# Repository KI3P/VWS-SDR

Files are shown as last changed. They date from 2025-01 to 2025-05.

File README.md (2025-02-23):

# Vienna Wireless Society Software Defined Receiver (VWS-SDR)

This repository contains the files for a 2025 project by the [Vienna Wireless Society's](https://viennawireless.net/wp/) Makers Group. This project aims to build the RF front end of a software defined receiver covering the HF bands. The goals of the project are: 

1. Learn how to use KiCAD, and 
2. Learn surface mount assembly techniques. 

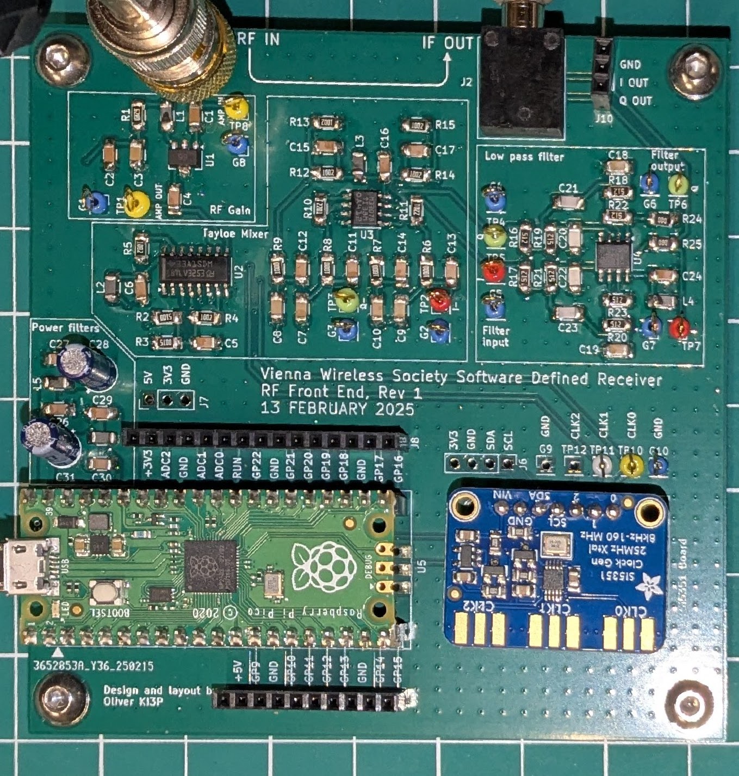
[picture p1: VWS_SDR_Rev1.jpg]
Photo of the VWS SDR


## Credit

The VWS-SDR design draws heavily from the RF board of the T41-EP Software Defined Transceiver (SDT) originally designed by Al Peter-AC8GY and Jack Purdum-W8TEE. The T41-EP is a self-contain SDT that does not require an external PC, laptop, or tablet to use. Al and Jack wrote a book, available on [Amazon](https://www.amazon.com/dp/B0D25FV48C), describing the theory and operation of the T41-EP.

Thanks to Rick W1DSP for writing the Quisk integration, Barry KV4FV for the gnuradio demodulation flowgraph, the many T41 contributors for the hardware and software derived from that project, and to Leon NT8B, Dean KK4DAS, Mark KM4GML, Vlad K4LRZ, and Ed KQ4RVX for their help designing, building, and testing the prototypes.

## Design overview 

The VWS-SDR has stages shown in the block diagram below.

1. A gain stage based on the [GALI-S66+](https://www.minicircuits.com/WebStore/dashboard.html?model=GALI-S66%2B) MMIC amplifier.
2. A [Tayloe Mixer](http://norcalqrp.org/files/Tayloe_mixer_x3a.pdf) that uses quadrature signals generated by a [Si5351](https://www.digikey.com/en/htmldatasheets/production/1316951/0/0/1/si535x-tmstk) clock generator and a [74CBTLV3253](https://www.ti.com/product/SN74CBTLV3253) 2-channel analog multiplexer to mix the RF signals to IF.
3. An anti-aliasing low-pass filter followed by a USB soundcard to digitize the IF signal.
4. Demodulation is performed in software using [quisk](http://james.ahlstrom.name/quisk/) or [gnuradio](https://www.gnuradio.org/).

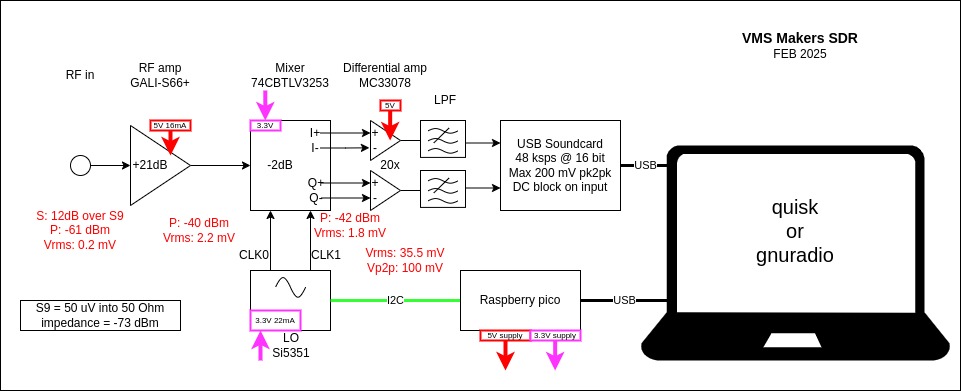
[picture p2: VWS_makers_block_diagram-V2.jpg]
Block diagram for the VWS SDR


To modify the PCB design, download this repository to your computer. Open the `KiCad\VWS-SDR-ref-design.kicad_pro` file using the [KiCad](https://www.kicad.org/) EDA software package. This repository includes a few custom symbols and footprints that should automatically be added to your library lists by KiCad.

## Code

### Pico

You two equivalent choices for the code that will run on the Pico. If you prefer C code written in the Arduino framework, use that. If you prefer micropython code, load that code instead. 

#### Arduino framework

The `code/pico_sketch` folder contains an Arduino sketch to program the Pico. The sketch listens for ASCII commands on the USB serial bus (baud 115200) that match this format:

`FR 123456`

where `123456` is the frequency in Hertz that the Si5351 should be tuned to.

Open the sketch in the Arduino IDE and configure Arduino to have the settings shown below under the Tools menu. For “Port” select whatever COM port appears when you plug the Pico into your computer with a USB cable.

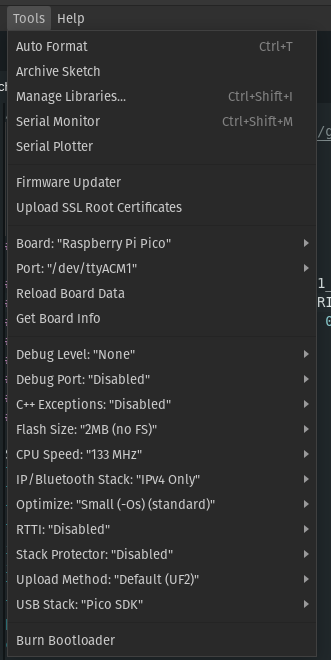
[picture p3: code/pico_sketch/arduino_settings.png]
Configuration settings for arduino


Then compile and load the sketch onto the pico by clicking the Upload button (Sketch->Upload).

The Pico sketch configures the Si5351 to produce 10 MHz tones on start. You can confirm this by connected an oscilloscope to the CLK0 and CLK1 outputs where you should see something like the screen shot below.

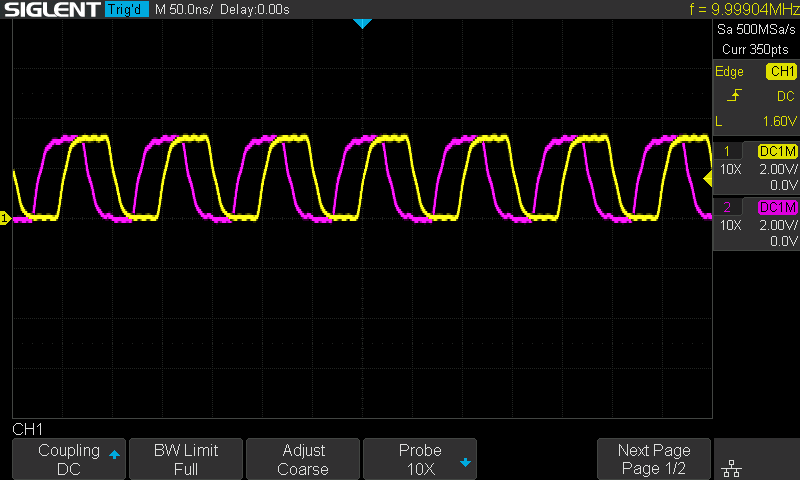
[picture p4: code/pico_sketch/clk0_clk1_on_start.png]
CLK0 and CLK1 on start


You can manually change the frequency using the Serial Monitor window in the Arduino. The Pico communicates at a baud rate of 115200 and expects commands in the form: “FR 123456” where 123456 is the frequency in Hz.

For instance, to tune the center of the band to 7070 kHz, enter the following command:

Update the tune frequency using the Arduino serial monitor

You should get the reply “OK” and an invitation to enter a new frequency. The CLK0 and CLK1 outputs should now show an output at 7070 kHz.

The expected response when updating the frequency

#### Micropython framework

The `code/pico_micropython` folder contains micropython code for the Pico written by Rick W1DSP. It works similarly to the Arduino sketch, the only difference is commands are terminated by a newline (`\n`) in the Python code, versus carriage return (`\r`) in the sketch. If the preferred tuner is the sketch, just edit this line in `code/VWS-Quisk/vwsquiskpkg/quisk_hardware.py`:

```python
   self.serial.write(b'FR %d\r'%(vfo+correction))
```

And change to `\r` to `\n`.  The original thinking in using Python for the VWS was to facilitate the extensive driver libraries Adafruit provides for their peripherals, as well as the ease of use and velocity of development Python brings to low speed control applications.

To install the Python tuner, the Pico must first be loaded with CircuitPython as described [here](https://learn.adafruit.com/getting-started-with-raspberry-pi-pico-circuitpython/circuitpython). Once CircuitPython is installed and booted, you will see a virtual disk drive for the board appear.  On my machine it is `/media/rick/CIRCUITPY`.

To run the tuner, copy `code/pico_micropython/{code.py,vws_tuner.py}`
to the virtual disk drive, and power cycle the board.  To verify operation, connnect to the serial port associated with the board (here, it is `/dev/ttyACM0`, 115200 bps), and type a carriage return.  You should see a `tune>` prompt, and entering a command like `FR 7074000` will cause the 5351 to tune to 7.074 Mhz. As required by the VWS SDR designs, clk0/clk1 are in quadrature. The Python script works similarly to various 5351 libraries to generate quadrature clocks: PLLA is a integer multiple of the desired frequency (factor of 4).

### Computer

Demodulation of the audio can be done in gnuradio or Quisk.

#### Gnuradio

Credit to Barry KV4FV for his contributions to the gnuradio code.

The `code/gnuradio_KI3P` contains a [gnuradio](https://wiki.gnuradio.org/index.php/InstallingGR) flowgraph to display the received signal and perform audio demodulation. It also allows you to adjust the gain and phase balance between the L and R channels to improve sideband separation if needed.

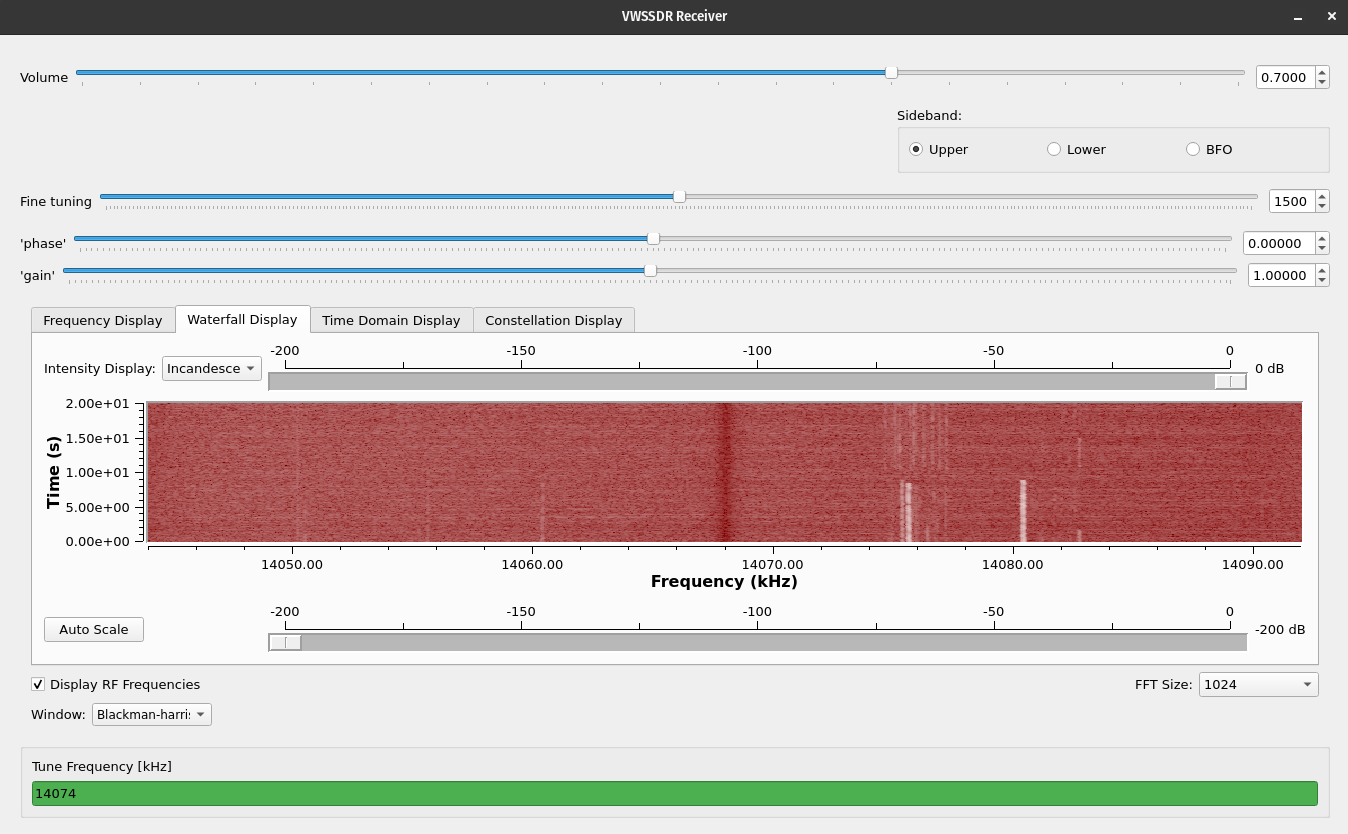
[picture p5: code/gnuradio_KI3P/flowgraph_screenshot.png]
Screenshot of the gnuradio flowgraph


#### Quisk

Credit to Rick W1DSP for the Quisk code and instructions. Quisk links:

* [Quisk documentation](https://james.ahlstrom.name/quisk/docs.html)
* [Quisk github](https://github.com/jimahlstrom/quisk)
* [Install Quisk](https://james.ahlstrom.name/quisk/docs.html#Installation)

##### Install VWS-Quisk package

Once quisk is installed, copy the `code/VWS-Quisk/vwsquiskpkg` directory into the quisk distribution directory. On my computer this is:

* `/usr/lib/python3/dist-packages/quisk`

Note: This is the way new radios are introduced to the quisk radio configuration manager: for a new radio named `xyzzy`, you create a directory named `xyzzypkg` in the quisk directory, and write a `quisk_hardware.py` module.  Python class inheritance will define most of the necessary routines, but functionally you'll want open/close/tune method as shown in the `vwsquiskpkg` version.

##### Configure Quisk

Launch quisk.

To add the VWS SDR as a radio, click the Config Button, then select the Radios tab. In the Radios config panel, select the "Add a new radio with the general type", and select the VWS SDR item, name the radio "VWS"

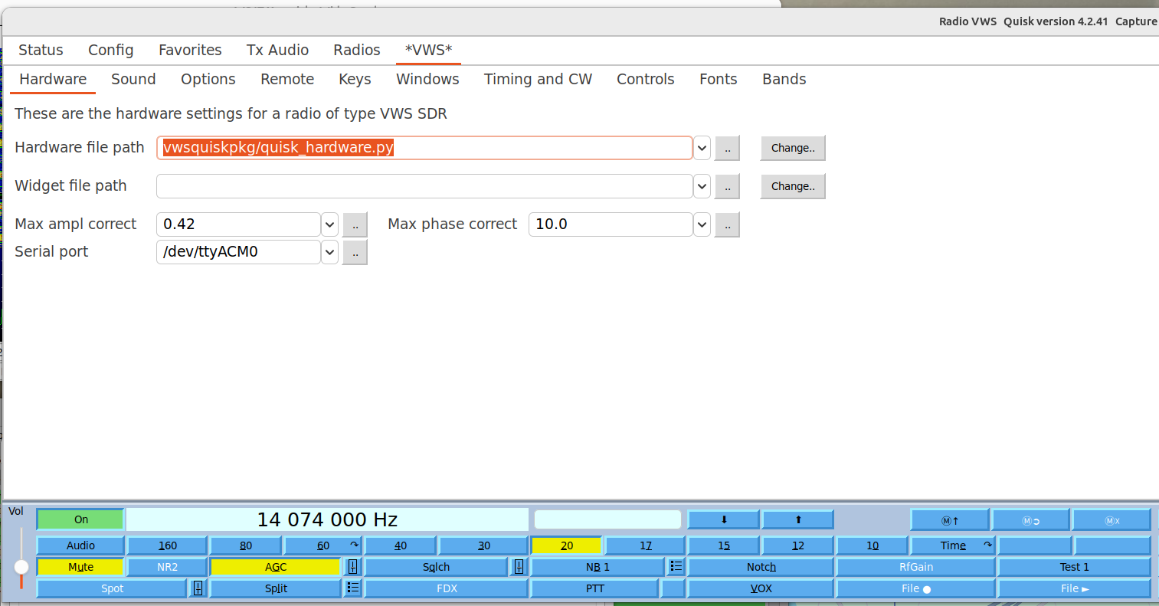
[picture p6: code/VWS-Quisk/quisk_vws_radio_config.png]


You should see a new Radio appear just below the title bar named "VWS".  Click that item, and then select the Hardware tab.  Enter the serial port name (in my case it was `/dev/ttyACM0`). Click the Sound tab, and choose appropriate settings for "Radio Sound Output" and "Microphone Input" that correspond to your soundcard.  In Digital Rx0 line, select `pulse: Use name QuiskDigitalOutput.monitor`.  Of course, you'll need to have loaded the pulse audio system.  Note that I have not tested any of this on Mac or Windows, and wouldn't expect it to work out of the box on either system type.

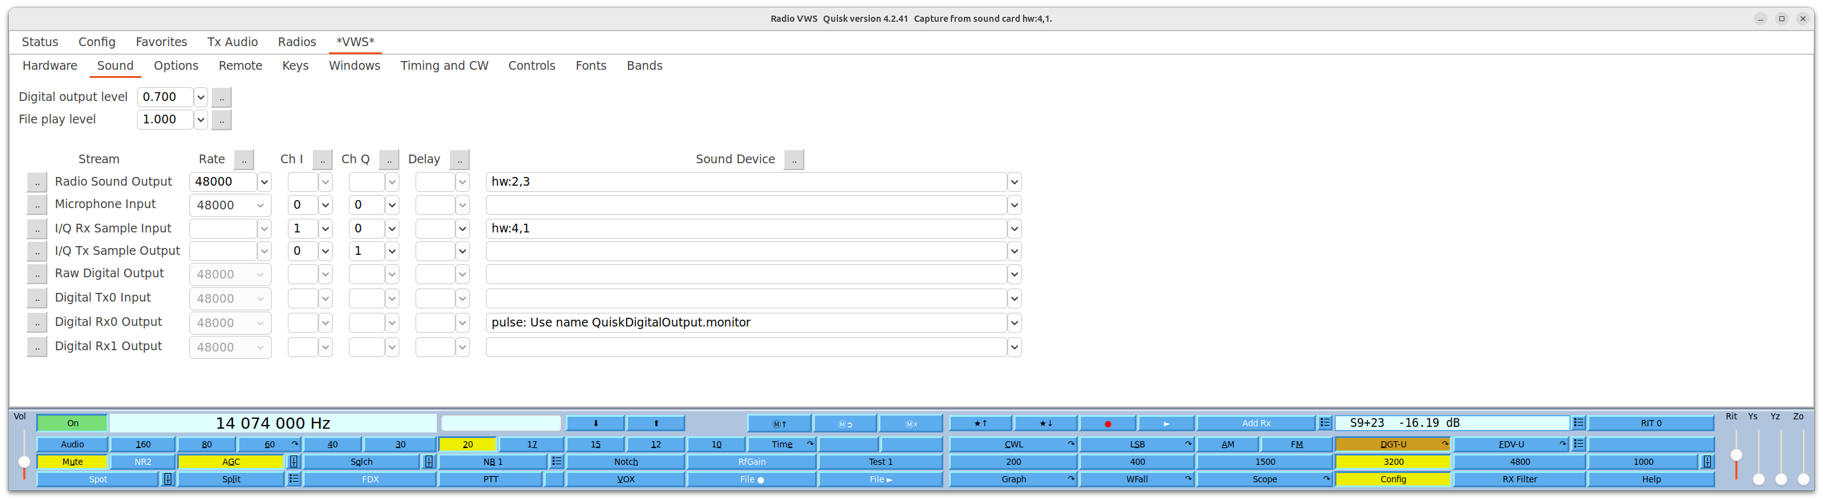
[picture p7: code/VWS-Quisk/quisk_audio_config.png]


Back on the Config->Radios screen, select VWS in the "When Quisk starts, use the radio" line. In the Config tab, quisk provides the ability to adjust IQ balance via "Adjust receive amplitude and phase".  I manually adjusted this using a signal generator tuned to the vicinity of 14.074 mhz, and then saved the result.

##### Configure WSJT-X if desired

To use the WSJT-X integration, use the package manager to install wsjtx, or build from source. 

I've been starting wsjtx manually within quisk: Click Config, select the Config tab, then look for the Start WSJT-X item.  The drop down menu has an option Main Rx0 Now item - select that and quisk will start the wsjtx application.  Once you've fully debugged the quisk:wsjtx integration,
setting "Start WSJT-X" to "Main Rx0 on startup" on the Config menus, Config tab will automatically start up wstjx when quisk starts.

The included screen captures show some of the details of getting quisk to interoperate with wsjtx.  Note that quisk won't stream audio on `QuiskDigitalOutput.monitor` unless you're in a digital mode (see DGT-U).

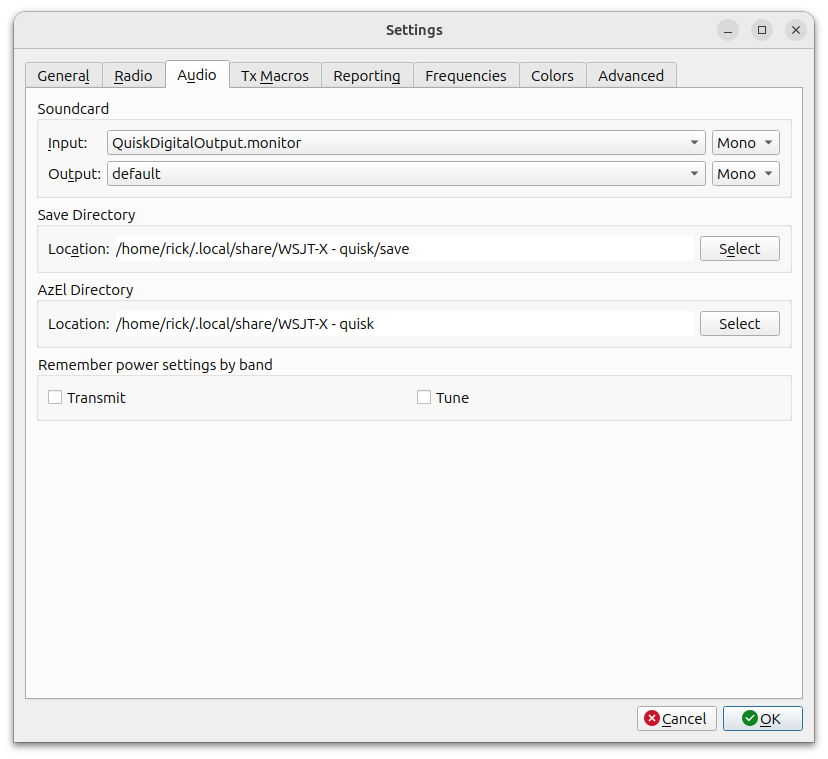
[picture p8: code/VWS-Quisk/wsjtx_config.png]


Quisk can be controlled by hamlib.  In the Config screens, select the VWS radio, then Remote tab.  On the Remote config screen, set the port to 4532.  You'll have to restart quisk for the setting to take effect.  After this is done, you can use `rigctl -m 2` to test: for example, the command `F 14074000` will tune quisk to the FT8 band on 20M.  Once the hamlib integration has been confirmed as working, you'll be able to control quisk via the wsjtx application, i.e. switching bands, frequencies in that app, and quisk following along as a normal radio would.

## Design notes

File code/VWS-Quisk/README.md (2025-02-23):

Lab notebook on how I got quisk to operate with the VWS-SDR:

---- Install tuner software on VWS SDR
I use a Python tuner on the Pico to tune the SDR.  It works similarly to the Arduino sketch in the
KI3P git repo, the only difference is commands are terminated by a newline (\n) in the Python
code, versus carriage return (\r) in the sketch.  If the preferred tuner is the sketch, just
edit this line in vwsquiskpkg/quisk_hardware.py:

   self.serial.write(b'FR %d\r'%(vfo+correction))

And change to \r to \n.  The original thinking in using Python for the VWS was to facilitate the
extensive driver libraries Adafruit provides for their peripherals, as well as the ease of use
and velocity of development Python brings to low speed control applications.

To install the Python tuner, the Pico must first be loaded with CircuitPython as described
here https://learn.adafruit.com/getting-started-with-raspberry-pi-pico-circuitpython/circuitpython.
Once CircuitPython is installed and booted, you will see a virtual disk drive for the board
appear.  On my machine it is /media/rick/CIRCUITPY.

To run the tuner, copy vws_tuner/{code.py,vws_tuner.py}
to the virtual disk drive, and power cycle the board.  To verify operation, connnect to the
serial port associated with the board (here, it is /dev/ttyACM0, 115200 bps), and type a
carriage return.  You should see a tune> prompt, and entering a command like FR 7074000
will cause the 5351 to tune to 7.074 mhz.  As required by the VWS SDR designs, clk0/clk1
are in quadrature.  The Python script works similarly to various 5351 libraries to generate
quadrature clocks: PLLA is a integer multiple of the desired frequency (factor of 4).

My eventual goal is to eliminate the need for a sound board and get IQ sent over USB to quisk
directly.  The current state of CircuitPython may not support bulk data transfer via USB, and
if so, I'll likely switch to using the Raspi SDK to write an appropriate driver.

---- Install quisk
Quisk documentation:  https://james.ahlstrom.name/quisk/docs.html
Quisk github: https://github.com/jimahlstrom/quisk
Build Quisk according to https://james.ahlstrom.name/quisk/docs.html#Installation

Once quisk is built, copy the included vwsquiskpkg directory into the quisk distribution directory (I run
quisk in the build location).

Note: This is the way new radios are introduced to the quisk radio configuration manager: for a new radio
named xyzzy, you create a directory named xyzzypkg in the quisk directory, and write a quisk_hardware.py
module.  Python class inheritence will define most of the necessary routines, but functionally you'll want
open/close/tune method as shown in the vwsquiskpkg version.

From the command line "python3 quisk.py" will start quisk.

---- Configure Quisk
To add the VWS SDR as a radio, click the Config Button, then select the Radios tab.
In the Radios config panel, select the "Add a new radio with the general type", and select the VWS SDR item,
name the radio "VWS"

You should see a new Radio appear just below the title bar named "VWS".  Click that item,
and then select the Hardware tab.  Enter the serial port name (in my case it was /dev/ttyACM0).
Click the Audio tab, and choose appropriate settings for "Radio Sound Output" and "Microphone
Input".  In Digital Rx0 line, select pulse: Use name QuiskDigitalOutput.monitor.  Of couse,
you'll need to have loaded the pulse audio system.  Note that I have not tested any of this
on Mac or Windows, and wouldn't expect it to work out of the box on either system type.

Back on the Config Radios screen, select VWS in the "When Quisk starts, use the radio" line.

In the Config tab, quisk provides the ability to adjust IQ balance via "Adjust receive amplitude
and phase".  I manually adjusted this using a signal generator tuned to the vicinity of 14.074 mhz,
and then saved the result.

---- Configure WSJT-X if desired
To use the WSJT-X integration, use the package manager to install wsjtx, or build from source.

I've been starting wsjtx manually within quisk: Click Config, select the Config tab, then look for the
Start WSJT-X item.  The drop down menu has an option Main Rx0 Now item - select that and
quisk will start the wsjtx application.  Once you've fully debugged the quisk:wsjtx integration,
setting "Start WSJT-X" to "Main Rx0 on startup" on the Config menus, Config tab will automatically
start up wstjx when quisk starts.

The included screen captures show some of the details of getting quisk to interoperate with
wsjtx.  Note that quisk won't stream audio on QuiskDigitalOutput.monitor unless you're
in a digital mode (see DGT-U).

Quisk can be controlled by hamlib.  In the Config screens, select the VWS radio, then
Remote tab.  On the Remote config screen, set the port to 4532.  You'll have to restart
quisk for the setting to take effect.  After this is done, you can use rigctl -m 2 to
test: for example, the command "F 14074000" will tune quisk to the FT8 band on 20M.  Once
the hamlib integration has been confirmed as working, you'll be able to control quisk
via the wsjtx application, i.e. switching bands, frequencies in that app, and quisk following
along as a normal radio would.

----
I've not provided a "LICENSE" for any of this work, as it is mostly just a few learnings about
how to get Quisk working with the VWS SDR.  Any IP contained herein may be used for free and
for any purpose, and as usual, I'm to be held harmless for its use.

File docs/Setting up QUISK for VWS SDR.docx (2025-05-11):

Setting up QUISK for VWS SDR

KK4DAS – 5/11/2025

1. Install python (add python to PATH, use admin privileges)
  a. Python Release Python 3.13.2 | Python.org (https://www.python.org/downloads/release/python-3132/)
2. Install quisk:
  a. Run PowerShell (not PowerShell ISE)
  b. Confirm Python version:
    i. python –version
  c. Install quisk
    i. python -m pip install --upgrade pip python -m pip install --upgrade setuptools python -m pip install --upgrade wxPython python -m pip install --upgrade pyserial python -m pip install --upgrade quisk
3. Add a desktop shortcut. Right click on the desktop and select New -> Shortcut. In the popup windows enter “python -m quisk” and hit Next, on the next screen enter “Quisk” and press finish.
4. Install the VWS radio package in the quisk installation directory
  a. To find the quisk installation directory right click on the new shortcut and select “Properties”. Look for the “Start in” field. This is the Python installation directory. Here is what it looks like on mine:
  b. C:\Users\dsoul\AppData\Local\Programs\Python\Python313
  c. In your file manager navigate to that directory, then navigate to the folder “Lib/site-packages/quisk”. This is the Quisk installation directory.
  d. Copy the folder “vwsquisk” package from the project folder that you downloaded from github. Its in the folder ,,/code/VWS-Quisk.
5. ---- Configure Quisk
  a. To add the VWS SDR as a radio, click the Config Button, then select the Radios tab.
  b. In the Radios config panel, select the "Add a new radio with the general type", and select the VWS SDR item, name the radio "VWS" and click “Apply”
  c. Click “When Quist starts, use the radio” to VWS
  d. You should see a new Radio appear just below the title bar named "VWS". Click that item, and then select the Hardware tab. Enter the serial port name (in my case it was COM5).
  e. Click the Sound tab, and choose appropriate settings for "Radio Sound Output" and "Microphone Input". For Radio Sound Output choose whatever your default sound output is. To find the device to use for “Microphone Input” in Windows, open System -> Sound Settings and find the name of the Input device that shows up when you plug in your USB sound card or your default stereo microphone input if available. Back in Quisk select this on “Microphone Input”
  f. Verify that the sound rate for output and input are both 48000
  g. Scroll down… for “I/Q Rx Sample Input” change Channel I to 1, and Channel Q to 0
  h. Select the Waterfall button.
  i. Shutdown and restart Quisk for all changes to take effect and you should be up and running.
6. --- Troubleshooting
  a. If the COM port is not set right QUISK may not start. After configuration in the GUI QUISK settings are stored in your Documents folder in a file called: quisk_settings.json. You can edit that file with Notepad and make any changes you need there. You can also delete all quisk files in the Documents folder and then start QUISK again and re-do the configuration steps.
  b. If QUISK fails to start you can run QUISK from a command prompt to see the error messages. Open a Command Prompt and enter:

pythonw -m quisk

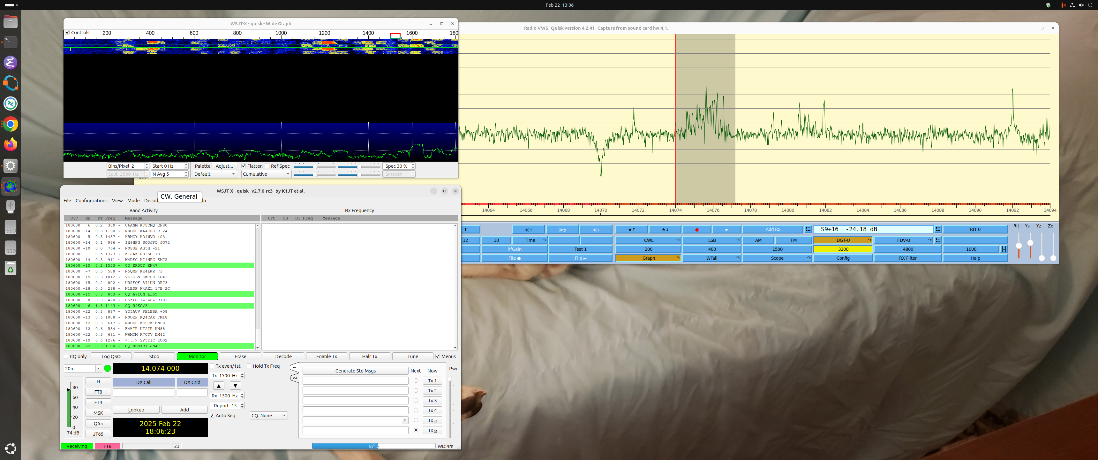
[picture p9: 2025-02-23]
code/VWS-Quisk/wsjtx_quisk_vws_sdr.png

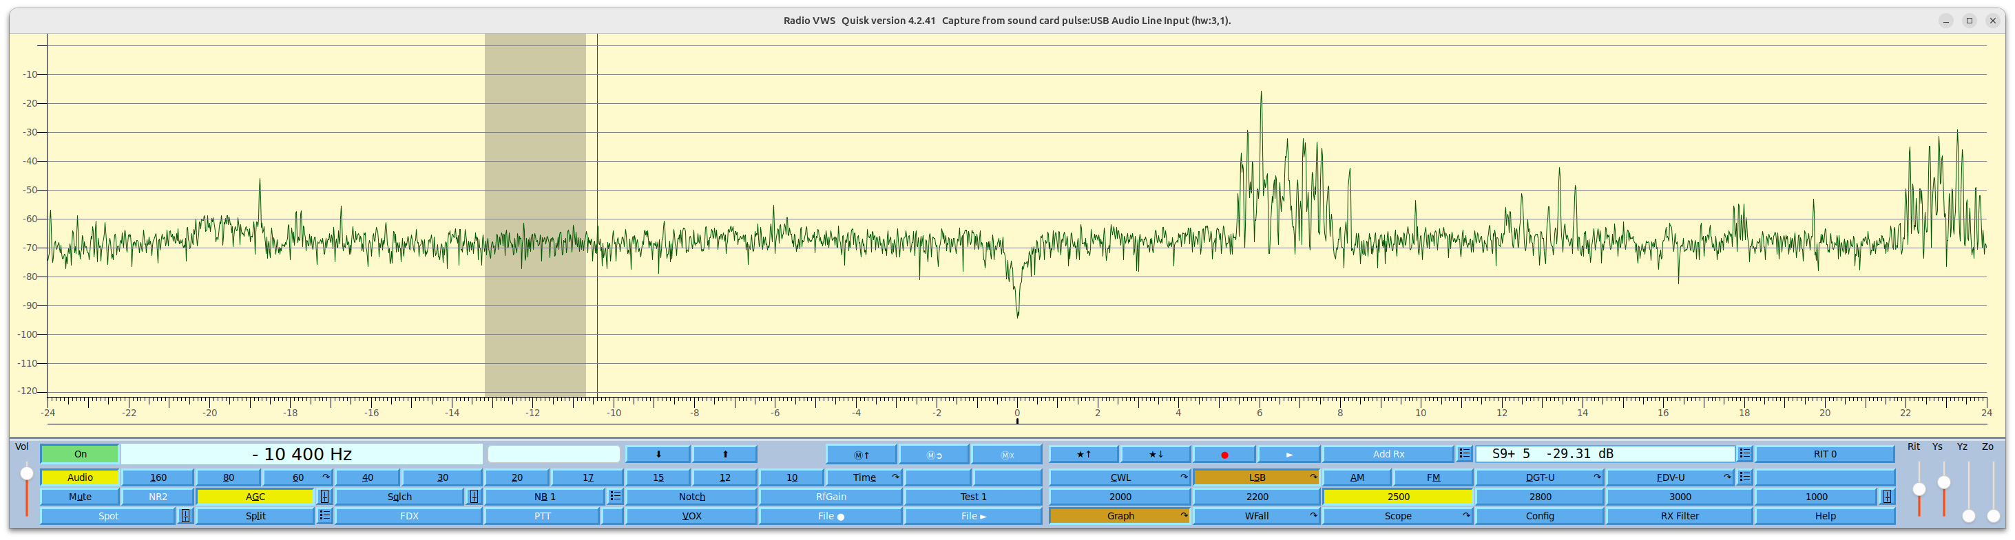
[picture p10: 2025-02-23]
code/VWS-Quisk/quisk_w1dsp_14070.png

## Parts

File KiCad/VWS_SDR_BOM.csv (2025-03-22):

Reference | Value | Footprint | Qty | DNP | Tayda | Adafruit PN | MPN
C1,C2,C4,C5,C6,C15,C16,C17,C24,C27,C30 | 0.1uF | Capacitor_SMD:C_1206_3216Metric_Pad1.33x1.80mm_HandSolder | 11 |  |  |  | C1206C104K5RACTU
C3,C18,C19 | 10uF | Capacitor_SMD:C_1206_3216Metric_Pad1.33x1.80mm_HandSolder | 3 |  |  |  | C1206C106K4PACTU
C7,C8,C9,C10 | 1uF | Capacitor_SMD:C_1206_3216Metric_Pad1.33x1.80mm_HandSolder | 4 |  |  |  | KGM31HR71C105KU
C11,C12,C13,C14,C26,C29 | 10nF | Capacitor_SMD:C_1206_3216Metric_Pad1.33x1.80mm_HandSolder | 6 |  |  |  | C1206C103K5RAC7210
C20,C22 | 180pF | Capacitor_SMD:C_1206_3216Metric_Pad1.33x1.80mm_HandSolder | 2 |  |  |  | KGM31BCG2A181FT
C21,C23 | 105pF | Capacitor_SMD:C_1206_3216Metric_Pad1.33x1.80mm_HandSolder | 2 |  |  |  | C3216C0G2J101G060AA
C28,C31 | 4.7uF | Capacitor_THT:CP_Radial_D5.0mm_P2.00mm | 2 |  |  |  | ESK475M016AC3AA
D1 | 5V LED | LED_SMD:LED_1206_3216Metric_Pad1.42x1.75mm_HandSolder | 1 |  |  |  | APTD3216LCGCK
D2 | 3V3 LED | LED_SMD:LED_1206_3216Metric_Pad1.42x1.75mm_HandSolder | 1 |  |  |  | APTD3216LSYCK
D3 | Indicator | LED_SMD:LED_1206_3216Metric_Pad1.42x1.75mm_HandSolder | 1 |  |  |  | APTD3216LSYCK
G1,G2,G3,G4,G5,G6,G7,G8,G9,G10,TP1,TP2,TP3,TP4,TP5,TP6,TP7,TP8,TP10,TP11,TP12,TP19,TP20 | TestPoint | Connector_PinHeader_2.54mm:PinHeader_1x01_P2.54mm_Vertical | 23 | DNP
J1 | RF_IN | VWS-SDR:SMA_Vertical_and_Edgemount | 1 |  |  |  | CONSMA001-G
J2 | IQ_Out | VWS-SDR:Jack_3.5mm_STX-3081_Horizontal | 1 |  |  |  | SJ1-3515N
J3 | SI5351 board | VWS-SDR:Adafruit_Si5351 | 1 |  |  | 2045
J4,J5 | Conn_01x20_Socket |  | 2 |  | A-1310
J6 | I2C breakout | Connector_PinHeader_2.54mm:PinHeader_1x04_P2.54mm_Vertical | 1 | DNP
J7 | Power breakout | Connector_PinHeader_2.54mm:PinHeader_1x03_P2.54mm_Vertical | 1 | DNP
J8 | GPIO Breakout1 | Connector_PinSocket_2.54mm:PinSocket_1x15_P2.54mm_Vertical | 1 |  | A-1669
J9 | GPIO Breakout2 | Connector_PinSocket_2.54mm:PinSocket_1x10_P2.54mm_Vertical | 1 |  | A-1306
J10 | IF breakout | Connector_PinSocket_2.54mm:PinSocket_1x03_P2.54mm_Vertical | 1 |  | A-1069
L1 | 1.5uH | Resistor_SMD:R_1206_3216Metric_Pad1.30x1.75mm_HandSolder | 1 |  |  |  | LQM31PN1R5M00L
L2,L3,L4,L5,L6 | FB | Resistor_SMD:R_1206_3216Metric_Pad1.30x1.75mm_HandSolder | 5 |  |  |  | HZ1206E601R-10
R1 | 62R | Resistor_SMD:R_1206_3216Metric_Pad1.30x1.75mm_HandSolder | 1 |  |  |  | CR1206-FX-62R0ELF
R2,R3 | 510R | Resistor_SMD:R_1206_3216Metric_Pad1.30x1.75mm_HandSolder | 2 |  |  |  | CR1206-FX-5100ELF
R4,R5,R12,R13,R14,R15 | 10k | Resistor_SMD:R_1206_3216Metric_Pad1.30x1.75mm_HandSolder | 6 |  |  |  | CR1206-FX-1002ELF
R6,R7,R8,R9 | 100R | Resistor_SMD:R_1206_3216Metric_Pad1.30x1.75mm_HandSolder | 4 |  |  |  | CR1206-FX-1000ELF
R10,R11 | 2k2 | Resistor_SMD:R_1206_3216Metric_Pad1.30x1.75mm_HandSolder | 2 |  |  |  | CR1206-FX-2201ELF
R16,R17,R18,R19,R20,R21,R22,R23 | 5k1 | Resistor_SMD:R_1206_3216Metric_Pad1.30x1.75mm_HandSolder | 8 |  |  |  | CR1206-JW-512ELF
R24,R25 | 0 | Resistor_SMD:R_1206_3216Metric_Pad1.30x1.75mm_HandSolder | 2 |  |  |  | CRCW12060000Z0EAC
R26 | 3k | Resistor_SMD:R_1206_3216Metric_Pad1.30x1.75mm_HandSolder | 1 |  |  |  | CR1206-FX-3001ELF
R27,R28 | 1k5 | Resistor_SMD:R_1206_3216Metric_Pad1.30x1.75mm_HandSolder | 2 |  |  |  | CR1206-FX-1501ELF
TPa1 | LNA Bias | TestPoint:TestPoint_Pad_D1.5mm | 1
TPc1 | Mixer Enable | TestPoint:TestPoint_Pad_D1.5mm | 1
TPd1 | Mixer DC | TestPoint:TestPoint_Pad_D1.5mm | 1
TPe1 | Q offset | TestPoint:TestPoint_Pad_D1.5mm | 1
TPf1 | I offset | TestPoint:TestPoint_Pad_D1.5mm | 1
TPg1 | Amp DC | TestPoint:TestPoint_Pad_D1.5mm | 1
TPh1 | Filter DC | TestPoint:TestPoint_Pad_D1.5mm | 1
U1 | GALI-S66 | Package_TO_SOT_SMD:SOT-89-3 | 1 |  |  |  | GALI-S66+
U2 | 74CBTLV3253DR | Package_SO:SOIC-16_3.9x9.9mm_P1.27mm | 1 |  |  |  | SN74CBTLV3253DR
U3,U4 | MC33078 | Package_SO:SOIC-8_3.9x4.9mm_P1.27mm | 2 |  |  |  | MC33078DR
U5 | RASPBERRY-PICO | VWS-SDR:Raspberry_pico_pin_or_castellation_footprint | 1 |  |  |  | SC0915

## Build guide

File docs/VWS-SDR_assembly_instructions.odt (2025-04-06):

VWS SDR Assembly Instructions

V2, 5 April 2025

When soldering surface mount components by hand, start with the lowest profile components – those that stick out the least from the PCB. Once all surface mount components are soldered, proceed to the through hole components. If a surface mount component has one end connected to ground, solder that end first.

# Solder the surface mount components

1. Solder the SMD capacitors.
2. Solder the SMD resistors.
3. Solder the SMD inductors (L1 and FB).
4. Solder the semiconductors (U1 to U4)

For U1, the GALI-S66 amplifier, first solder pin 1 (indicated by the triangle on the silkscreen), followed by the pin 3 pad on the opposite side of the component. Then solder the center pad, which is connected to ground. Have patience when soldering the grounded pads – you will need to apply heat for much longer to achieve good solder flow because of the heat flow from the pads into the ground plane.

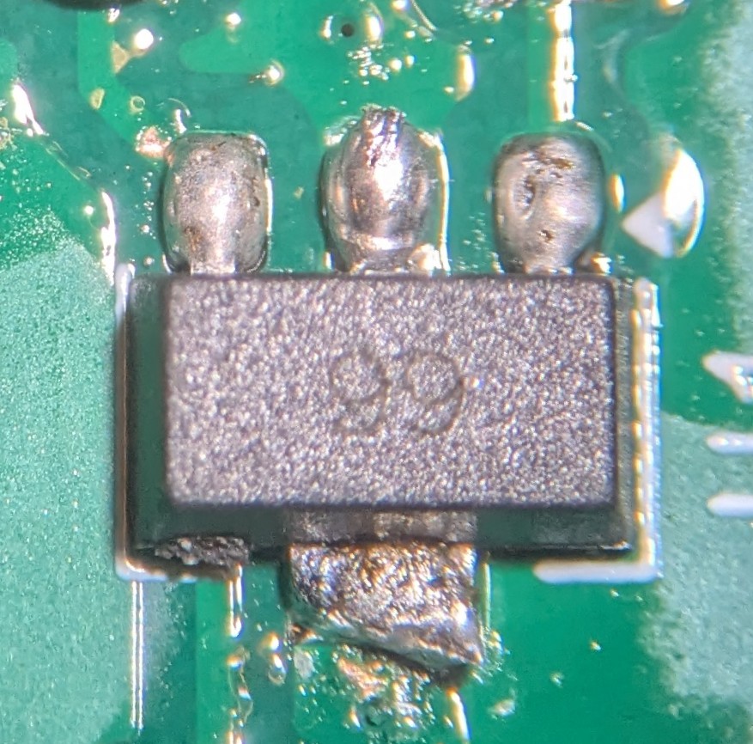
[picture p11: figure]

# Solder the through-hole components

1. Solder J2, the IF out connector.
2. Solder J3, the header pins for the Si5351 board.
3. If you want to use header sockets, solder them for the GPIO breakouts and the Pico. Otherwise, solder the header pins for the Pico.
4. Solder J1, the RF input SMA connector.
5. Solder C28 and C31, the through-hole capacitors.
6. Connect or solder the Pico and Si5351 boards.

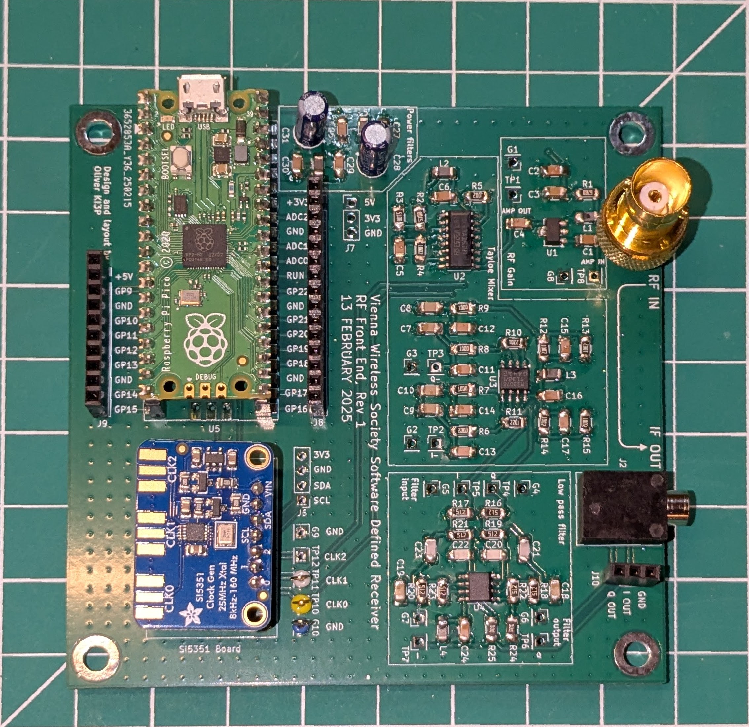
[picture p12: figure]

# Power on and test

The board should draw roughly 80 mA of current from the USB cable. Measure this with a USB current meter if you have one.

## Pico sketch

If you have a VWS-SDR kit, the Pico has been pre-loaded with the appropriate Arduino sketch. To get the latest version, download it from the following link:

https://github.com/KI3P/VWS-SDR/tree/main/

Click the green box that says CODE and select Download Zip and save the file on the computer. Unzip the file to wherever you want – you’ll need to navigate there to update the sketch.

## Installing and configuring the Arduino IDE

If you don’t have it first download and install the Arduino IDE:

https://www.arduino.cc/en/software

Start the Arduino IDE.

Install the board manager for the Raspberry PI Pico.

In the File menu select Preferences. A dialog box will open. In the field “Additional Board Manager URLs:” cut and paste the following link and click OK.

https://github.com/earlephilhower/arduino-pico/releases/download/global/package_rp2040_index.json

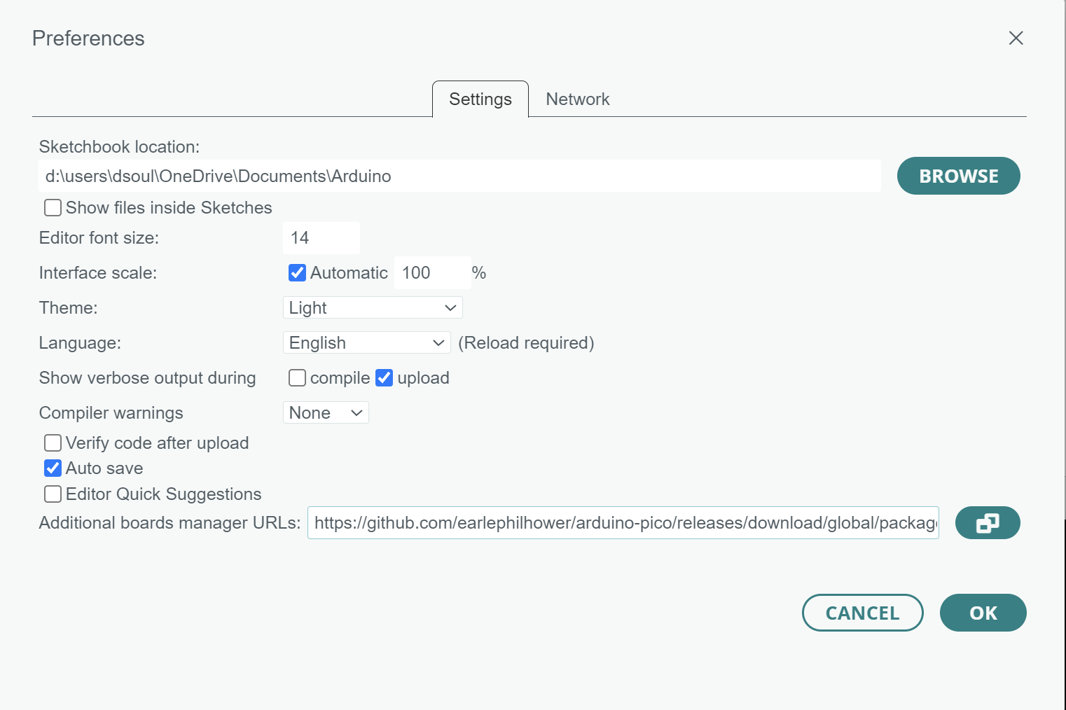
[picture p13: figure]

Next, go to Tools -> Boards -> Board manager and search for Pico and a list of board managers will appear. The one you want is “Raspberry PI Pico/RP2040 by Earle F. Philhower III”. Click INSTALL.

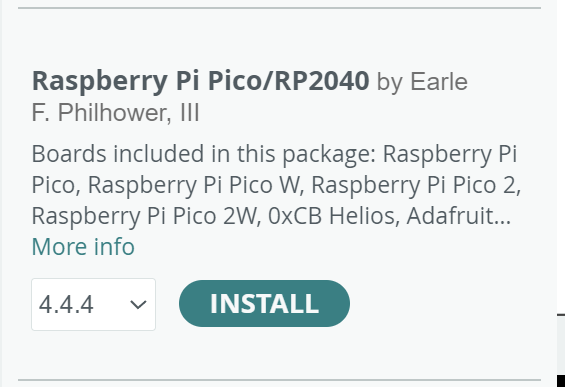
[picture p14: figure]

Now open the sketch. Navigate on your computer to the folder where you unzipped the code archive, find and open the pico sketch folder, then double click on pico_sketch.ino and the sketch will open in the Arduino IDE.

If you have not done so already, connect the Pico to your computer via a USB cable.

In the Arduino IDE go to Tools -> Board -> Board Manager -> Raspberry Pi Pico/RP2040 and select Raspberry Pi Pico.

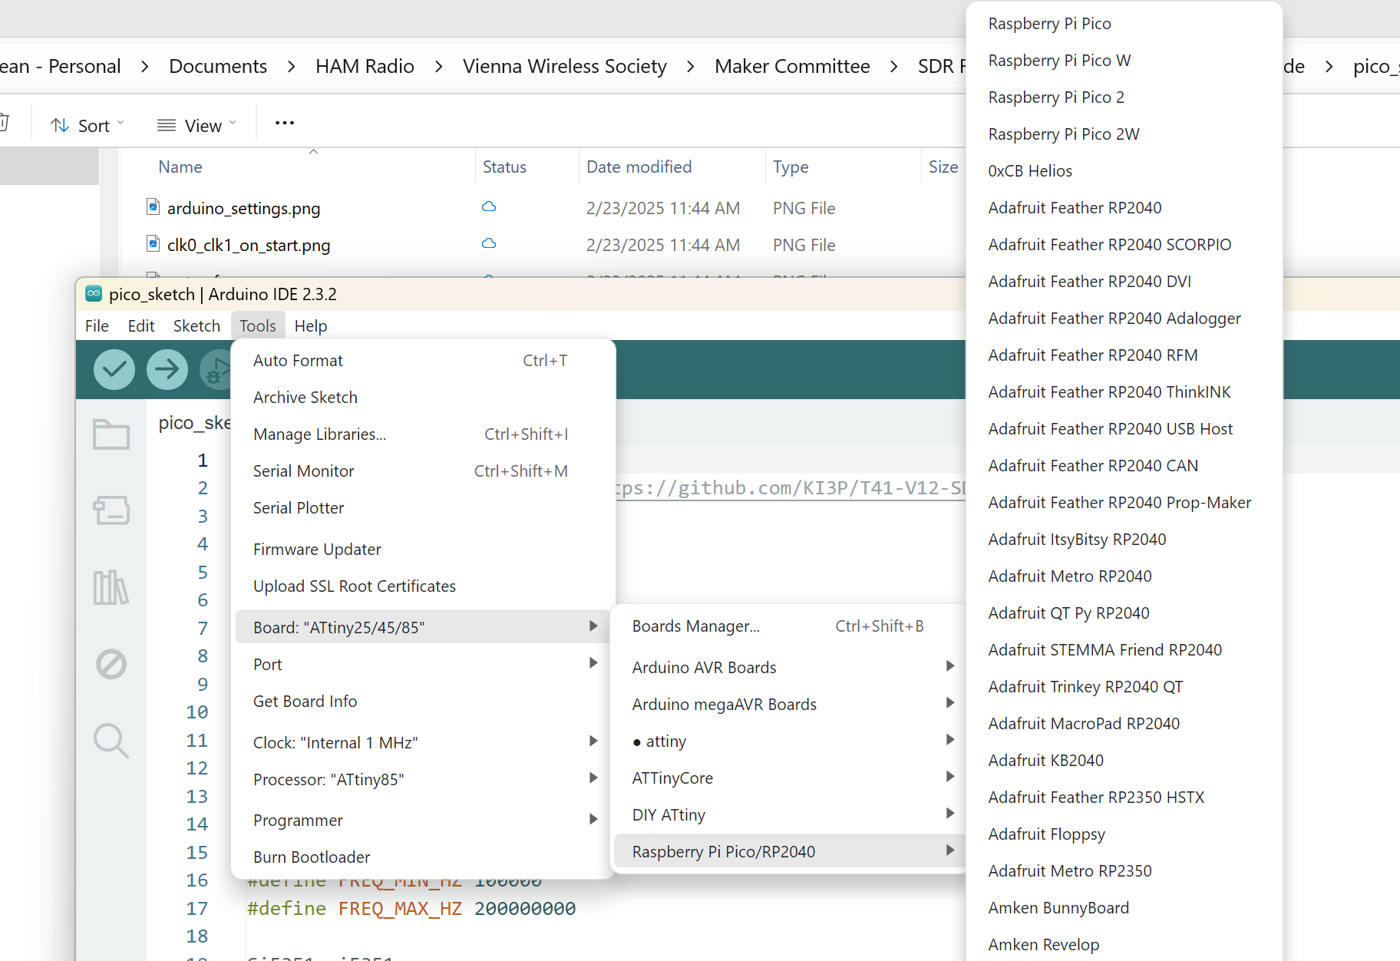
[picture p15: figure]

Open the sketch in the Arduino IDE and configure Arduino to have the settings shown below under the Tools menu. For “Port” select whatever COM port appears when you plug the Pico into your computer with a USB cable:

* Tools -> Port and select the COM port connected to the Pico.

To compile and upload the sketch to Pico, click the Right arrow on the top toolbar in the IDE.

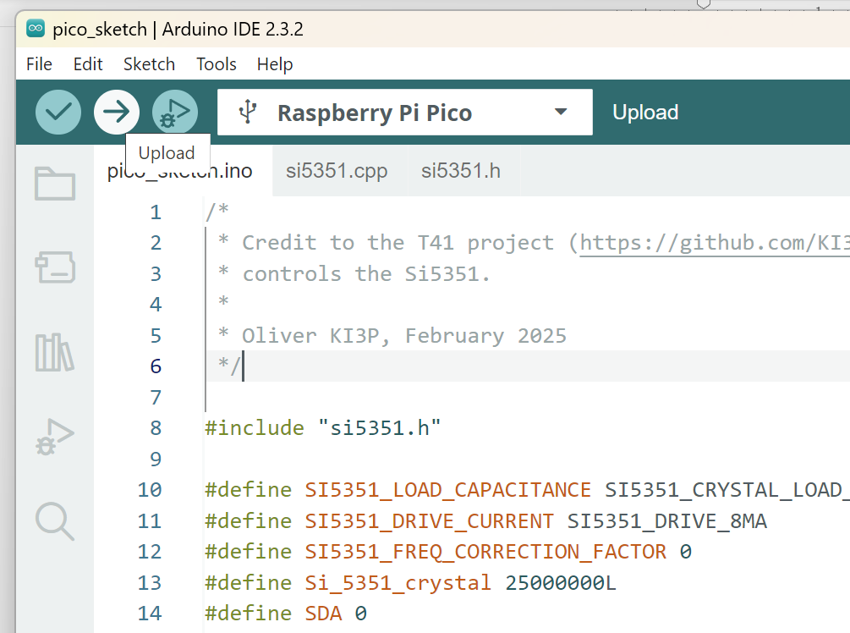
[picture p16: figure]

That’s it. You now have the latest sketch on the Raspberry PI Pico and you are ready to test and are all set for future updates.

## Testing

The Pico sketch configures the Si5351 to produce 10 MHz tones on start. You can confirm this by connecting an oscilloscope to the CLK0 and CLK1 outputs where you should see something like the screen shot below.


You can manually change the frequency using the Serial Monitor window in the Arduino. The Pico communicates at a baud rate of 115200 and expects commands in the form: “FR 123456” where 123456 is the frequency in Hz.

For instance, to tune the center of the band to 7070 kHz, enter the following command:

You should get the reply “OK” and an invitation to enter a new frequency. The CLK0 and CLK1 outputs should now show an output at 7070 kHz.

## Demodulation

Connect the IF output (J2) to the microphone input on the sound card of your computer. We will use gnuradio to test whether the SDR is producing signals that can be demodulated. The gnuradio sketch can be found at the following link:

https://github.com/KI3P/VWS-SDR/tree/main/code/gnuradio_KI3P

To install gnuradio on your computer follow these instructions:

https://wiki.gnuradio.org/index.php/InstallingGR

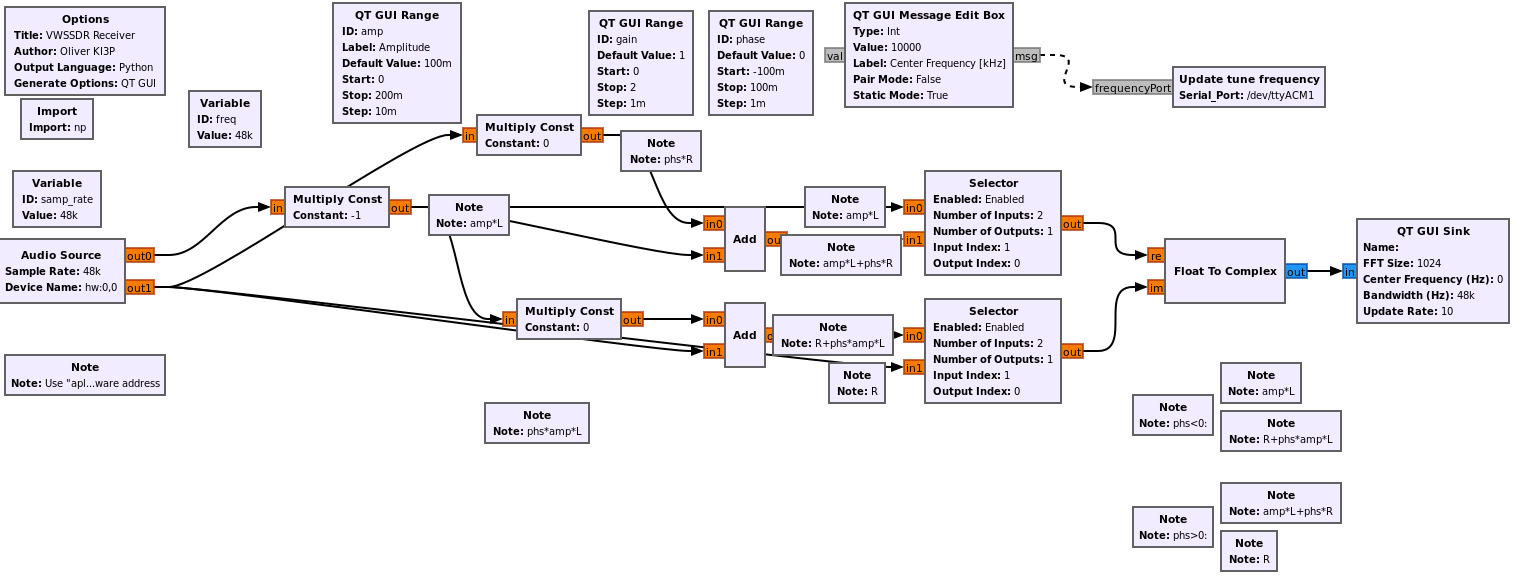
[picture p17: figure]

You will need to update two fields in the gnuradio sketch for your computer setup. The first is the address of the sound card in the Audio Source block on the left. By default it is set to the first audio device. This may work out of the box for your computer. If not, then you can use the “aplay -l” command in linux to find the hardware address of your sound card device.

To find the Microphone Input name in Windows, open Settings and go to System and then Sound. Look for the input devices and find the name windows uses for the device you are using and copy that into the GNU radio field. You can also rename the device to something there if that makes it easier.

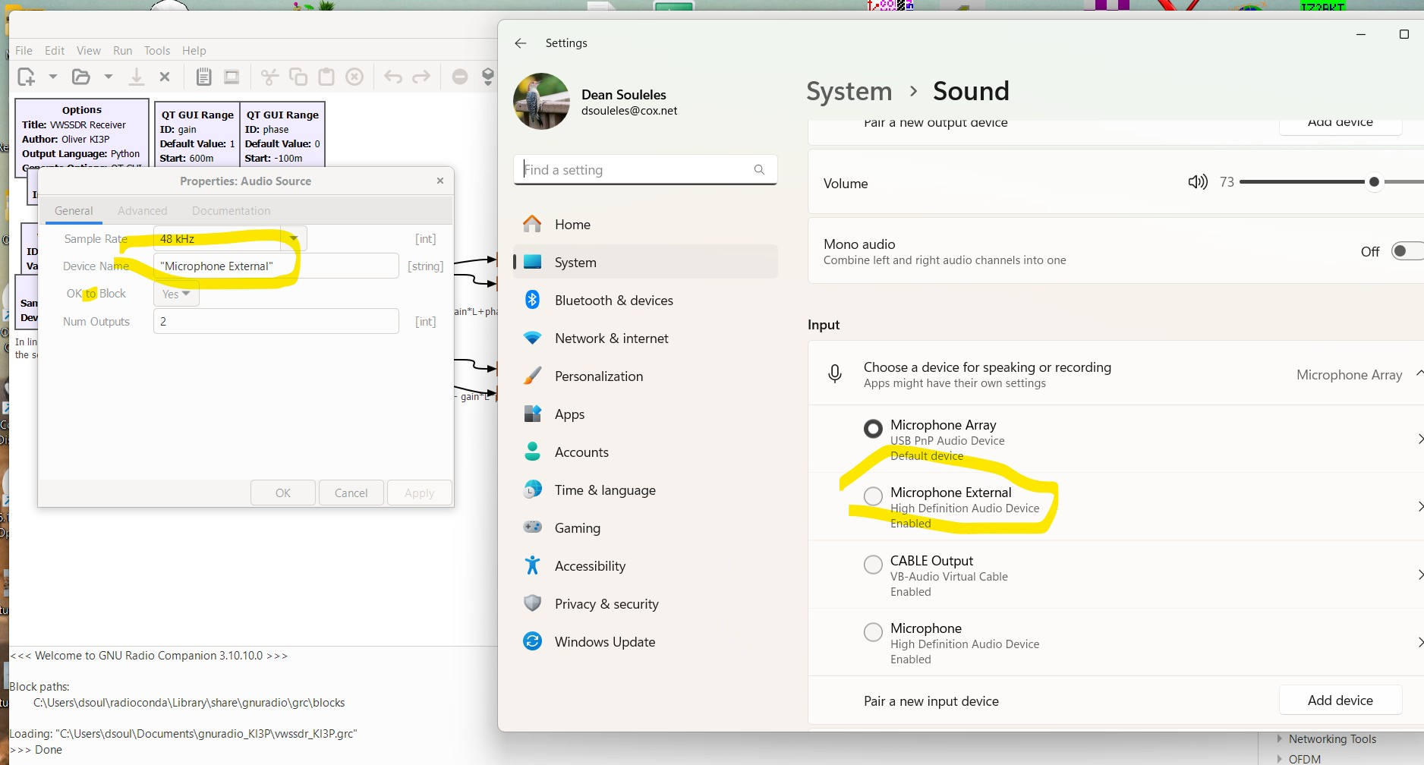
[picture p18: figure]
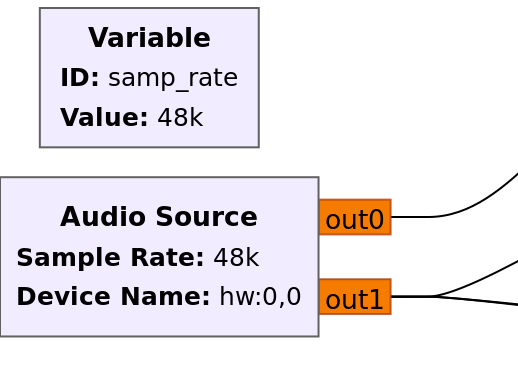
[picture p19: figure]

The second field that will need to be updated is the serial COM port address of the Pico.

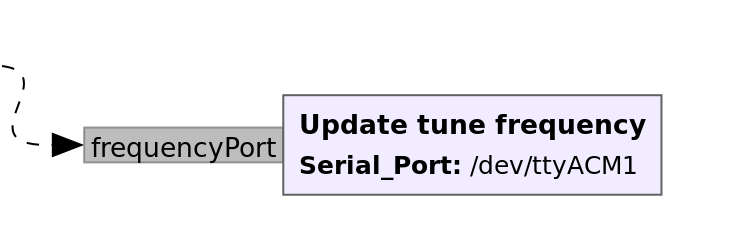
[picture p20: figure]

Enter whatever COM or serial port you used in the Pico sketch section above.

Once these fields are updated, launch the gnuradio sketch by clicking on Run → Execute or hitting the play button in the tool bar. Note that the Arduino IDE must be closed or you will get an error when both Arduino and gnuradio try to control the USB serial port.

Connect your antenna and change the center frequency to 7070 kHz in the green box. Change to the Waterfall Display tab and you should see the ever-present FT8.

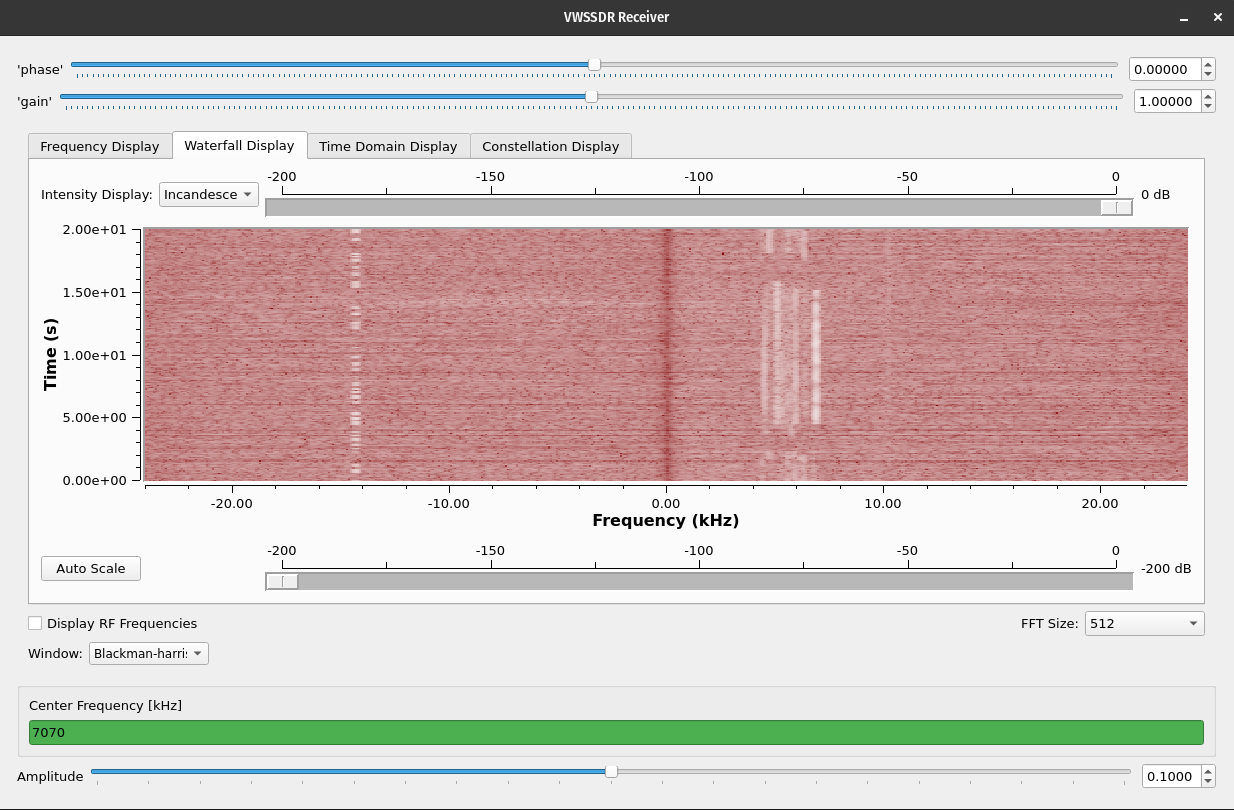
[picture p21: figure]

## Troubleshooting

(See separate testing guide for more)

1. Make sure the PC side of this is working. If you have a low frequency signal generator, use it to make a 5 kHz, 100 mV signal. Inject this into the audio cable that you're using to connect the SDR to your PC. You should see this tone in the gnuradio sketch.
2. If the above test works, then the problem must be on the board.
  a. Make sure that you're seeing 10 MHz signals on CLK0 and CLK1.
  b. Use a TinySA or RF signal generator to generate a -53 dBm signal at 10.005 MHz and inject it into J1 (this equates to 20dB over S9).
  c. Using an oscilloscope, start tracing the signal. I see the following:
    i. TP6: 1.1V peak to peak (380mV RMS) sine at ~8 kHz (my LO and generator have difference clocks, to the IF frequency not the expected 10 kHz)
    ii. TP4: 530 mV peak to peak (190mV RMS) sine at ~8 kHz.
    iii. TP3: ~30 mV peak to peak sine at ~8 Hz.
  d. Oscilloscopes like mine are too insensitive to probe weak RF signals, so a spectrum analyzer is needed if the problem lies in the pre-mixer part.

Signal 10.005MHz at -23dBm into J1

TP 8 & 1 -scope 100ns, 50mv scale

TP8: ??mV s/b 14mVpp

TP1: 140mVpp – 20dBm

TP3: 220mVpp @ 2.914MHz (???)

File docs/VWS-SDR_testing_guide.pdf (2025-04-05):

### VWS SDR Test Guide

V2, 5 April 2025

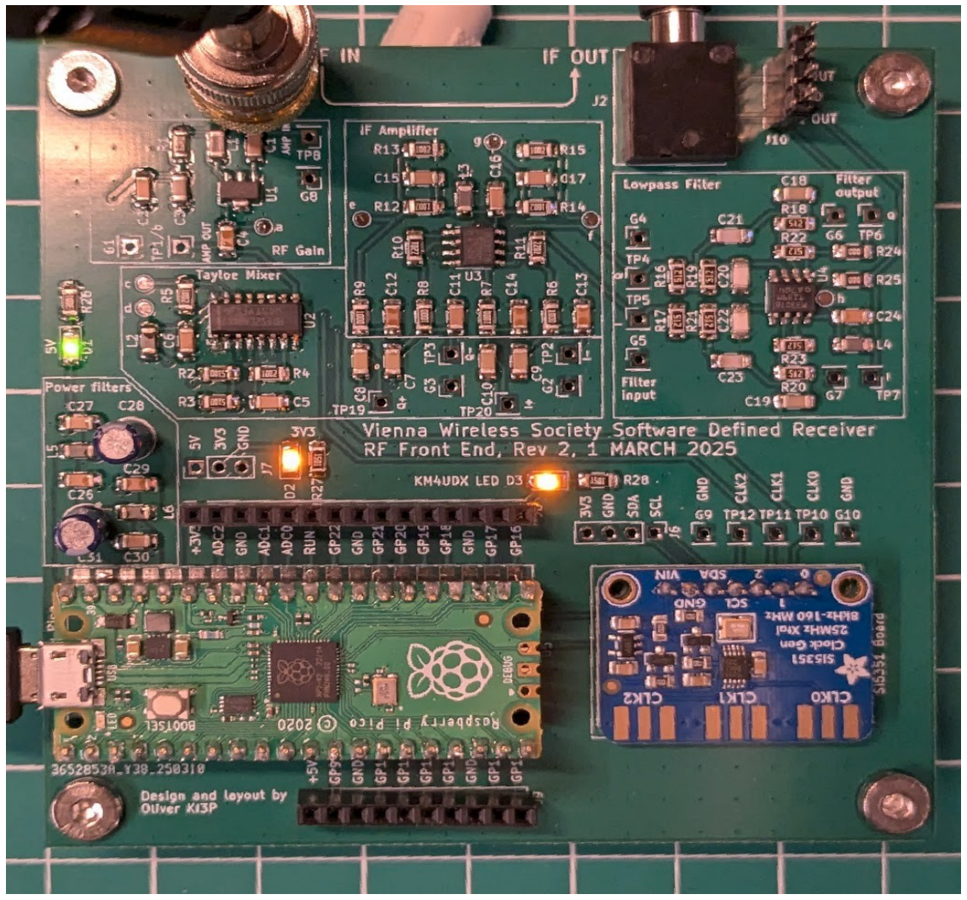
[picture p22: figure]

Current consumption

Upon being plugged in, the board should draw roughly 80 mA of current from the USB cable.

DC levels
Measure the DC voltage levels at the points indicated below and confirm that they are close to the values in the table.

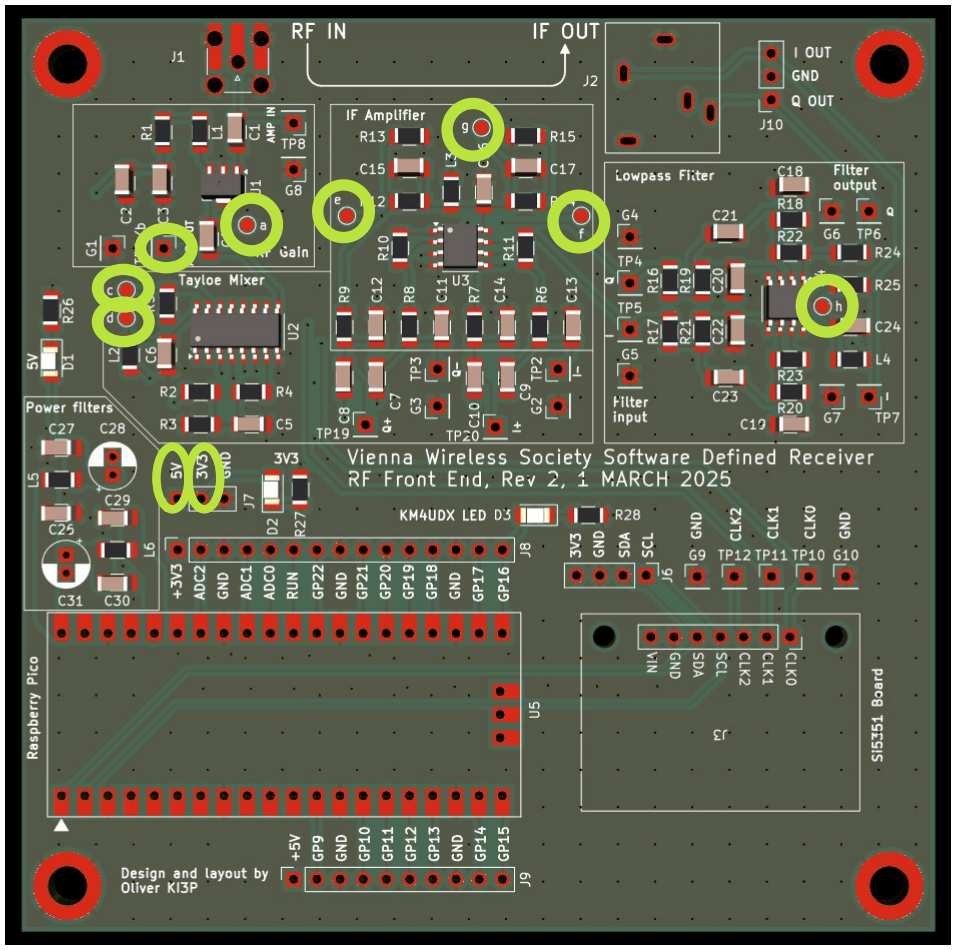
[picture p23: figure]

Test point | Description | Expected | Measured
5V | 5V rail | 5V
3.3V | 3.3V rail | 3.3V
a | LNA bias | 3.5 - 4V
b | Mixer bias | 1.65V
c | Mixer enable | 0V
d | Mixer DC | 3.3V
e | Q offset | 2.5V
f | I offset | 2.5V
g | Amplifier DC | 5V
h | Filter DC | 5V

RF levels
Test the RF performance by putting a known RF signal in and measuring it at various points through the circuit.
By default, the VWS SDR will tune to a frequency of 10,000 kHz.
Inject a signal at 10,005 kHz with an amplitude of -53 dBm.

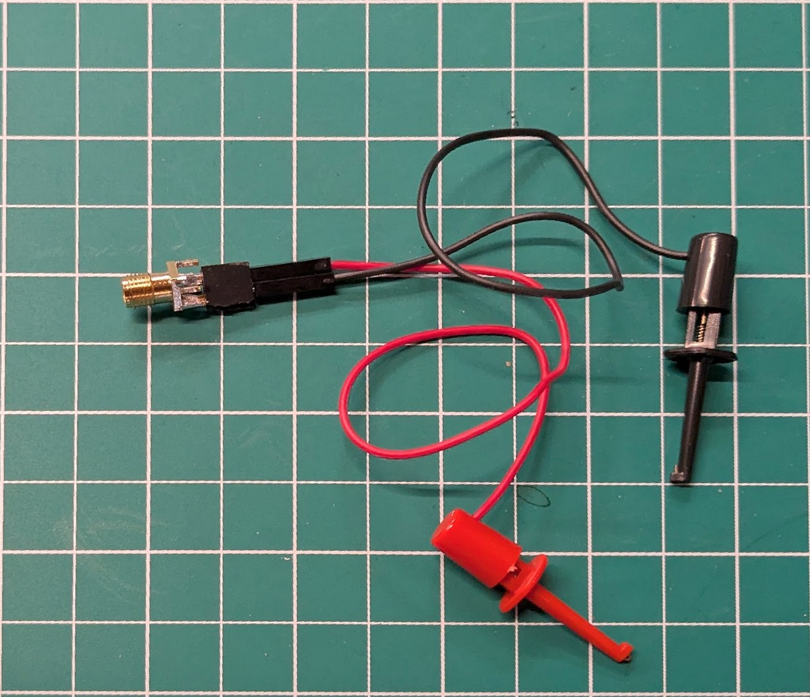
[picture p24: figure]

You can measure the RF power at TP8 and TP1 using some clips connected to an SMA connector as shown above.
On the prototype board I found the following signal levels. You should expect to see similar (but not identical) values on your board.
Test point | Vpp [mV] | Vrms [mV] | P [dBm] | Measured
TP8 (RF in) | | | -54.7
TP1 (after LNA) | | | -37.5
TP2/TP3 (I-,Q-) | 73 | 26.5
TP4/TP5 (after tayloe) | 566 | 200
TP6/TP7 (after LPF) | 1130 | 400

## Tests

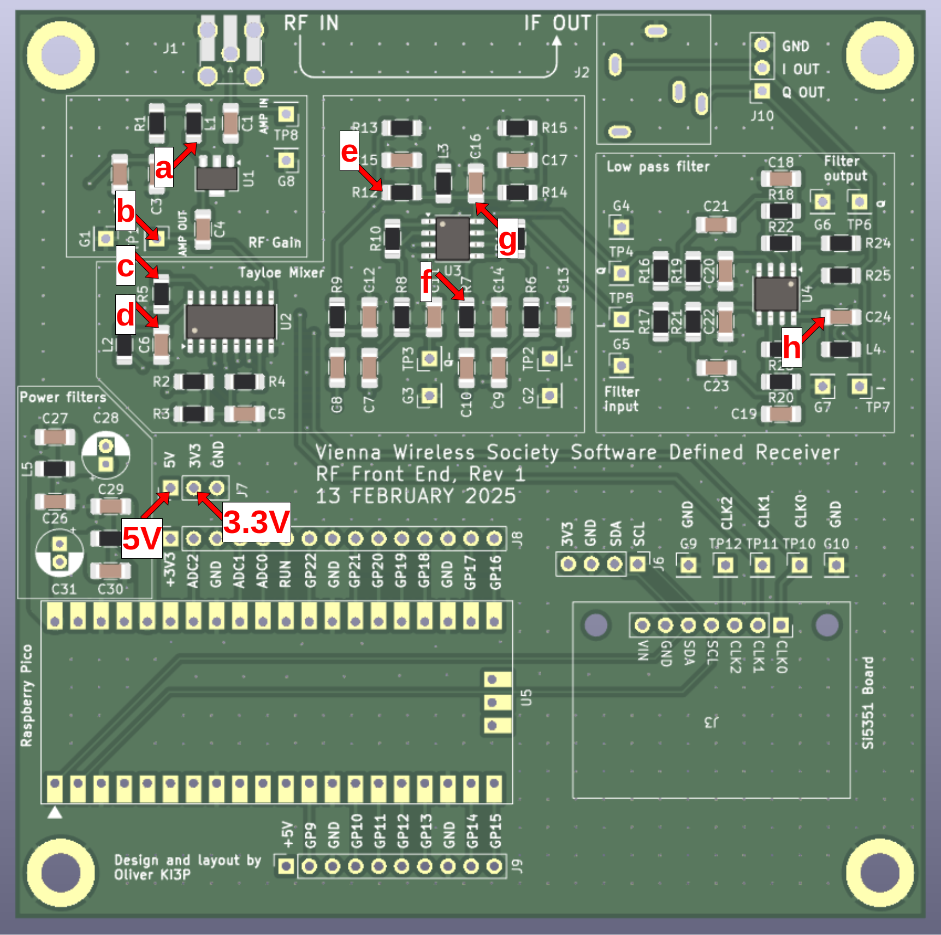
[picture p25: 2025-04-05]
docs/DC_test_points.png

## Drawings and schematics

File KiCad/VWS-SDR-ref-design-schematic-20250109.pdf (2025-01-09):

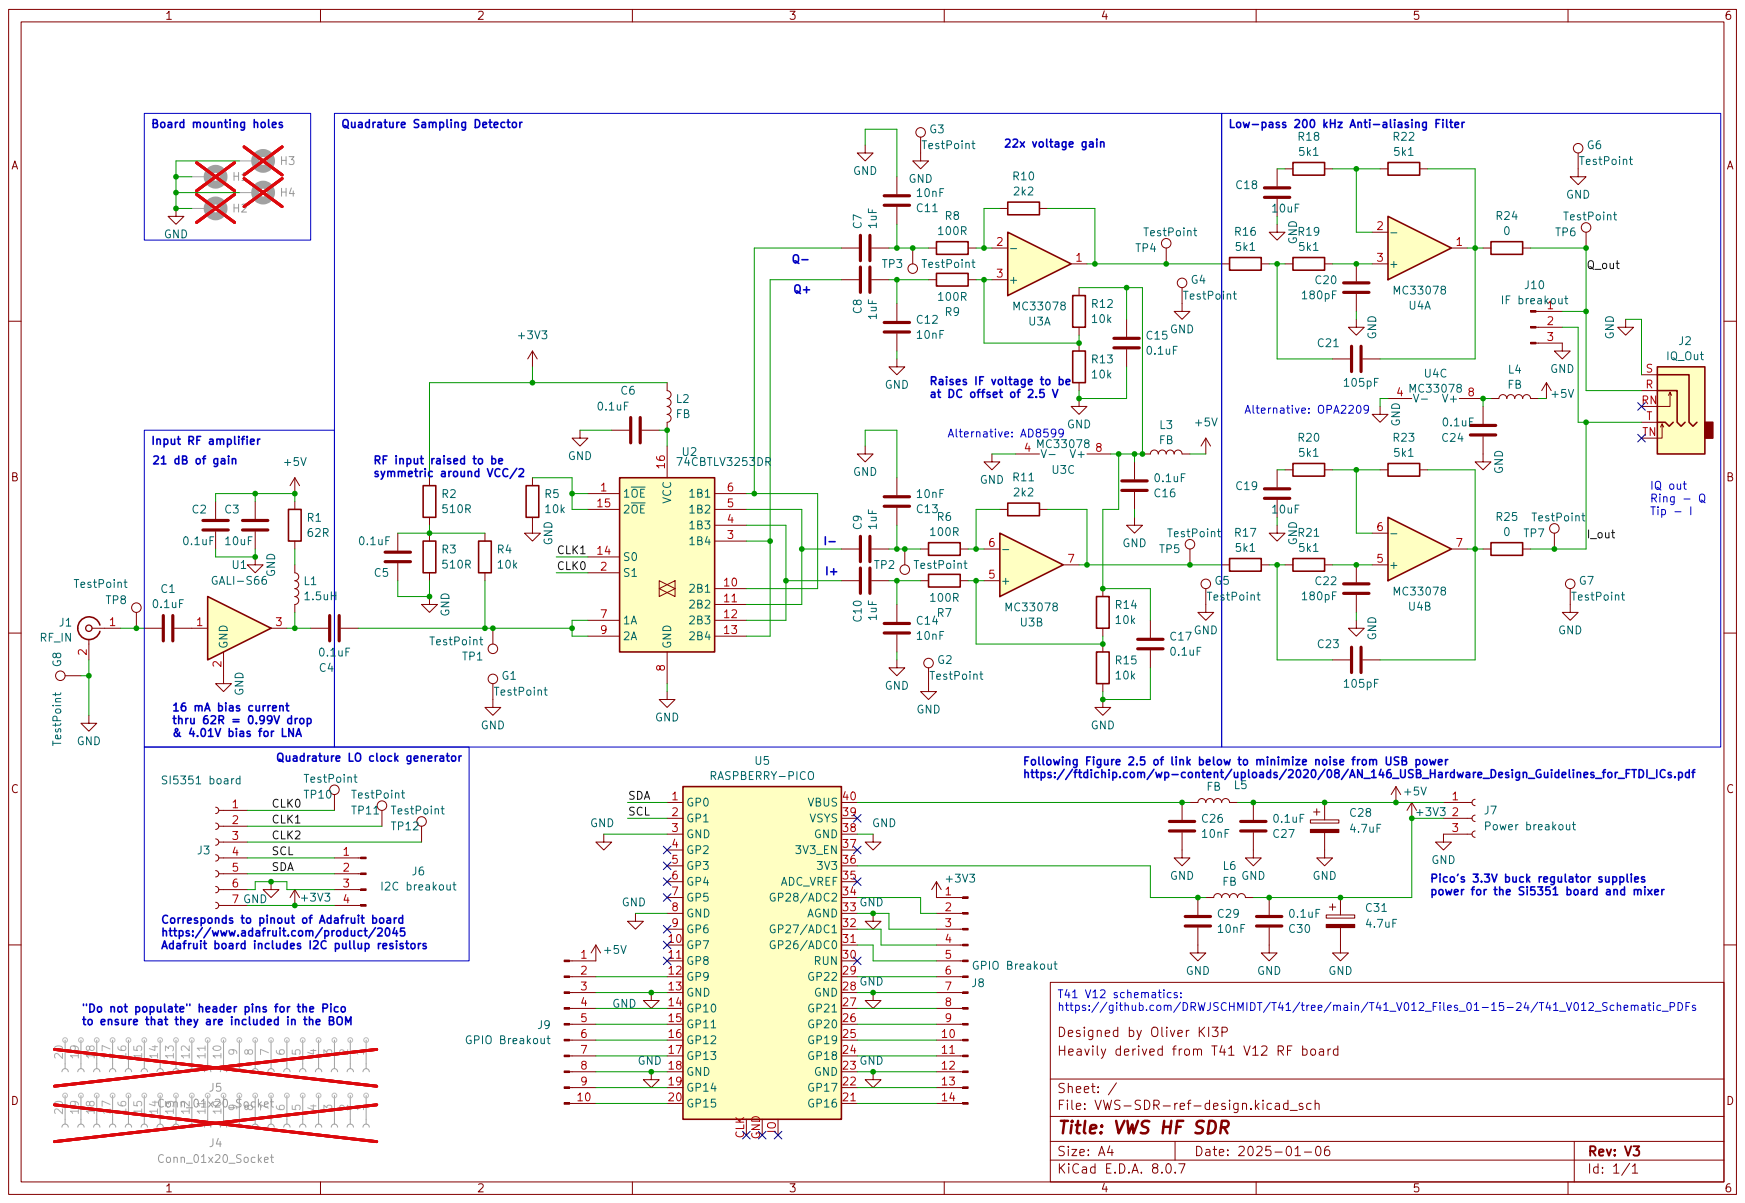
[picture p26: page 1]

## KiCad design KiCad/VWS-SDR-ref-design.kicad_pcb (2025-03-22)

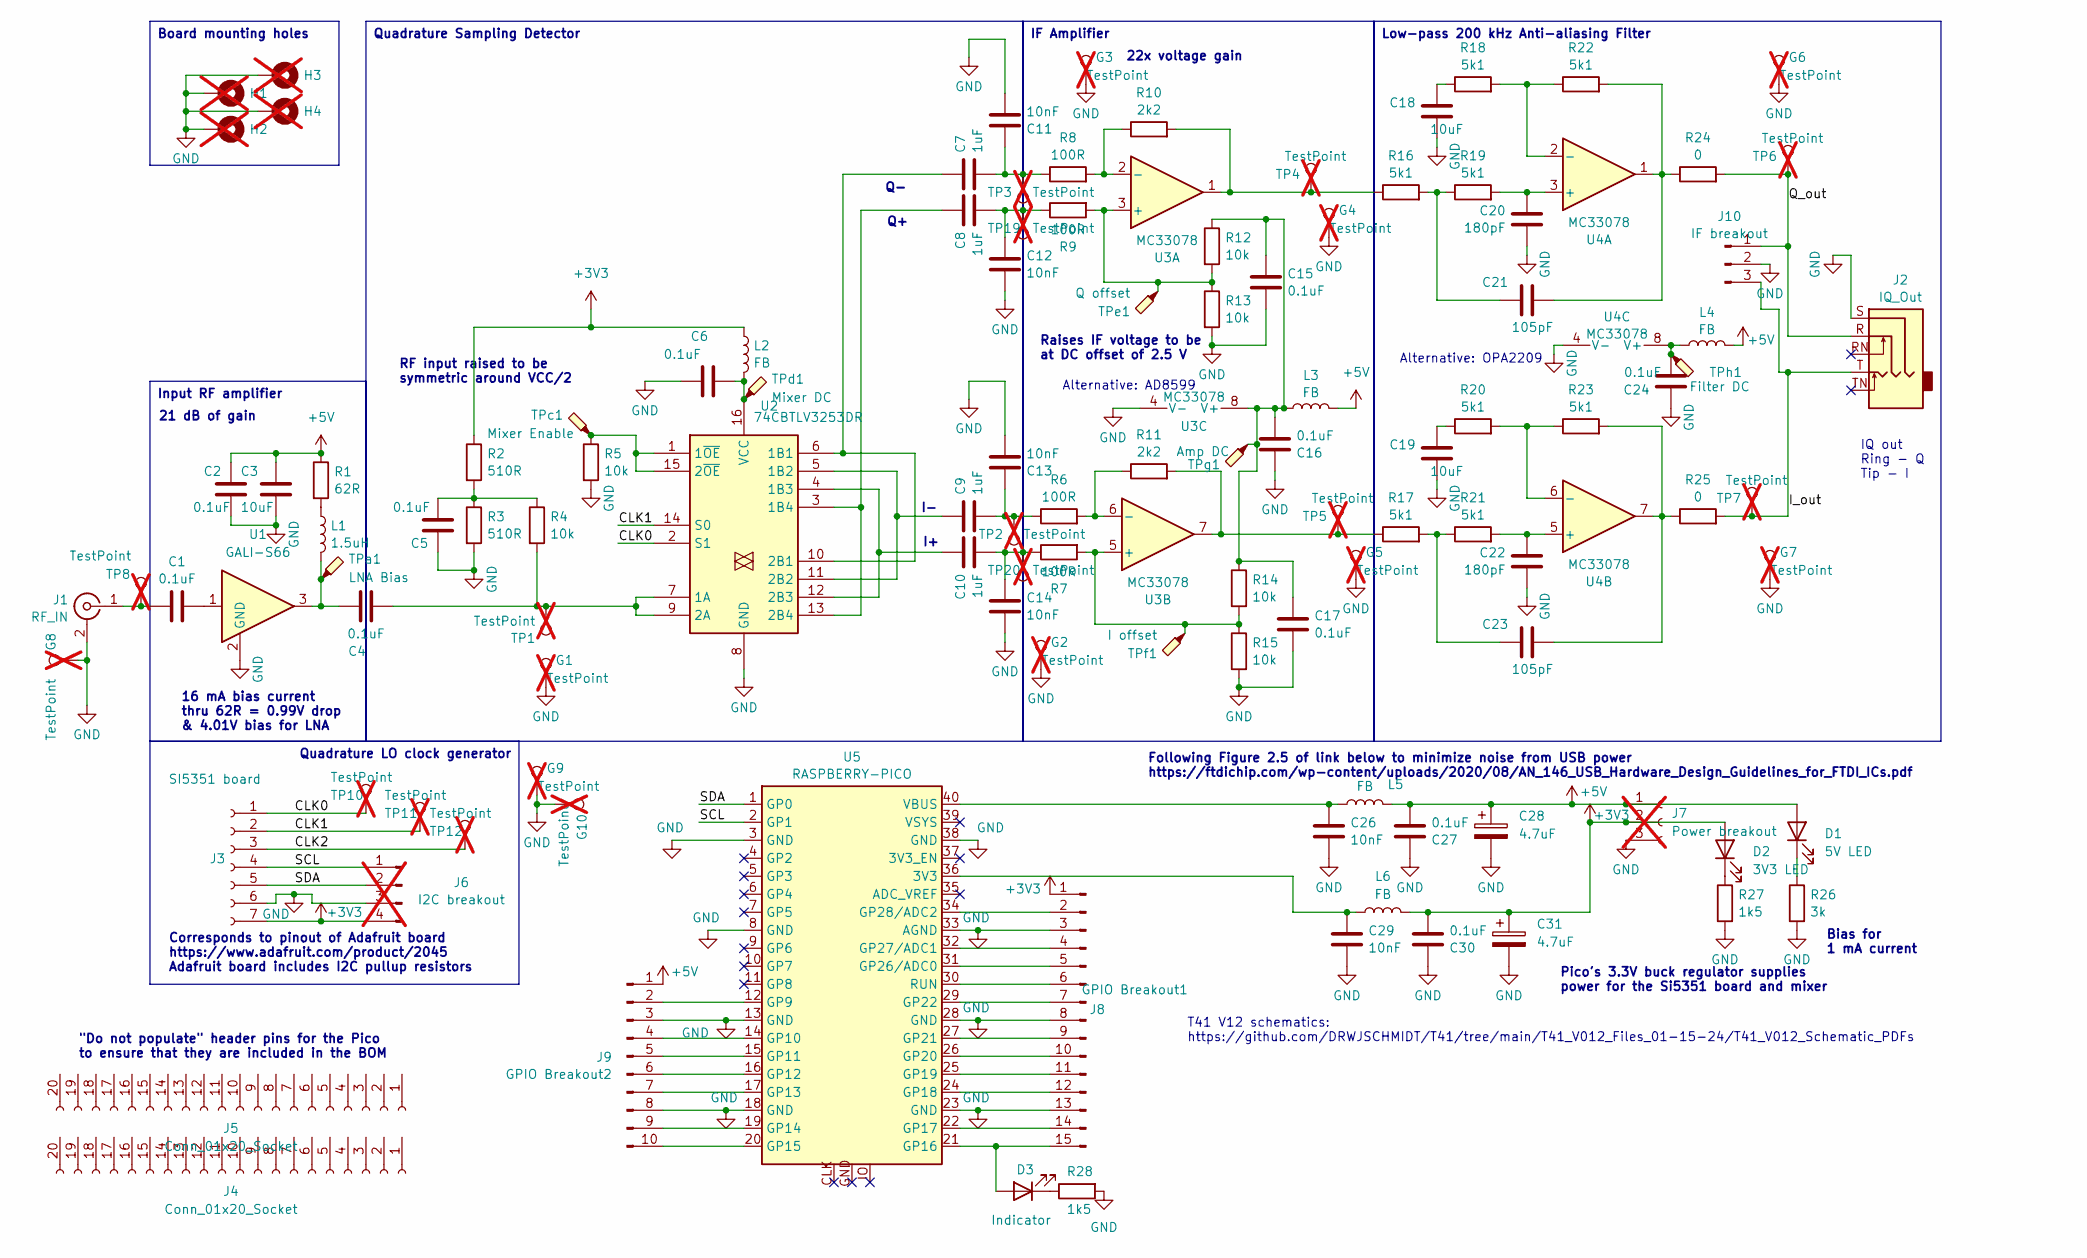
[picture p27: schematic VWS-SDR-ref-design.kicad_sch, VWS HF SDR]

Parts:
C1, C2, C4, C5, C6, C15, C16, C17, C24, C27, C30: 0.1uF; C_1206_3216Metric_Pad1.33x1.80mm_HandSolder; Mouser Part Number C1206C104K5RACTU
C3, C18, C19: 10uF; C_1206_3216Metric_Pad1.33x1.80mm_HandSolder; Mouser Part Number 80-C1206C106K4P
C7, C8, C9, C10: 1uF; C_1206_3216Metric_Pad1.33x1.80mm_HandSolder; Mouser Part Number 187-CL31B105KBHNNNE
C11, C12, C13, C14, C26, C29: 10nF; C_1206_3216Metric_Pad1.33x1.80mm_HandSolder; Mouser Part Number 80-C1206C103K5R7210
C20, C22: 180pF; C_1206_3216Metric_Pad1.33x1.80mm_HandSolder; Mouser Part Number 791-1206B181K160CT
C21, C23: 105pF; C_1206_3216Metric_Pad1.33x1.80mm_HandSolder; Mouser Part Number 581-12065C101KAT2A
C28, C31: 4.7uF; CP_Radial_D5.0mm_P2.00mm; Mouser Part Number 80-ESK475M016AC3AA
D1: 5V LED; LED_1206_3216Metric_Pad1.42x1.75mm_HandSolder; MPN APTD3216LCGCK
D2: 3V3 LED; LED_1206_3216Metric_Pad1.42x1.75mm_HandSolder; MPN APTD3216LSYCK
D3: Indicator; LED_1206_3216Metric_Pad1.42x1.75mm_HandSolder; MPN APTD3216LSYCK
G1, G2, G3, G4, G5, G6, G7, G8, G9, G10: TestPoint; PinHeader_1x01_P2.54mm_Vertical; not fitted
H1, H2, H3, H4: MountingHole_4.3mm_M4_DIN965_Pad; not fitted
J1: RF_IN; SMA_Vertical_and_Edgemount; Mouser Part Number 712-CONSMA001-G
J2: IQ_Out; Jack_3.5mm_STX-3081_Horizontal; Mouser Part Number 490-SJ1-3515N
J3: SI5351 board; Adafruit_Si5351
J4, J5: Conn_01x20_Socket
J6: I2C breakout; PinHeader_1x04_P2.54mm_Vertical; not fitted
J7: Power breakout; PinHeader_1x03_P2.54mm_Vertical; not fitted
J8: GPIO Breakout1; PinSocket_1x15_P2.54mm_Vertical
J9: GPIO Breakout2; PinSocket_1x10_P2.54mm_Vertical
J10: IF breakout; PinSocket_1x03_P2.54mm_Vertical
L1: 1.5uH; R_1206_3216Metric_Pad1.30x1.75mm_HandSolder; Mouser Part Number 81-LQM31PN1R5M00L
L2, L3, L4, L5, L6: FB; R_1206_3216Metric_Pad1.30x1.75mm_HandSolder; Mouser Part Number 875-HZ1206E601R-10
R1: 62R; R_1206_3216Metric_Pad1.30x1.75mm_HandSolder; Mouser Part Number 652-CR1206FX-62R0ELF
R2, R3: 510R; R_1206_3216Metric_Pad1.30x1.75mm_HandSolder; Mouser Part Number 652-CR1206FX-5100ELF
R4, R5, R12, R13, R14, R15: 10k; R_1206_3216Metric_Pad1.30x1.75mm_HandSolder; Mouser Part Number 652-CR1206FX-1002ELF
R6, R7, R8, R9: 100R; R_1206_3216Metric_Pad1.30x1.75mm_HandSolder; Mouser Part Number 652-CR1206FX-1000ELF
R10, R11: 2k2; R_1206_3216Metric_Pad1.30x1.75mm_HandSolder; Mouser Part Number 652-CR1206FX-2201ELF
R16, R17, R18, R19, R20, R21, R22, R23: 5k1; R_1206_3216Metric_Pad1.30x1.75mm_HandSolder; Mouser Part Number 652-CR1206JW-512ELF
R24, R25: 0; R_1206_3216Metric_Pad1.30x1.75mm_HandSolder; Mouser Part Number 71-CRCW12060000Z0EAC
R26: 3k; R_1206_3216Metric_Pad1.30x1.75mm_HandSolder; MPN CR1206-FX-3001ELF
R27, R28: 1k5; R_1206_3216Metric_Pad1.30x1.75mm_HandSolder; MPN CR1206-FX-1501ELF
TP1, TP2, TP3, TP4, TP5, TP6, TP7, TP8, TP10, TP11, TP12, TP19, TP20: TestPoint; PinHeader_1x01_P2.54mm_Vertical; not fitted
TPa1: LNA Bias; TestPoint_Pad_D1.5mm
TPc1: Mixer Enable; TestPoint_Pad_D1.5mm
TPd1: Mixer DC; TestPoint_Pad_D1.5mm
TPe1: Q offset; TestPoint_Pad_D1.5mm
TPf1: I offset; TestPoint_Pad_D1.5mm
TPg1: Amp DC; TestPoint_Pad_D1.5mm
TPh1: Filter DC; TestPoint_Pad_D1.5mm
U1: GALI-S66; SOT-89-3; Mouser Part Number 139-GALI-S66
U2: 74CBTLV3253DR; SOIC-16_3.9x9.9mm_P1.27mm; Mouser Part Number 595-SN74CBTLV3253DR
U3, U4: MC33078; SOIC-8_3.9x4.9mm_P1.27mm; Mouser Part Number 595-MC33078DR
U5: RASPBERRY-PICO; Raspberry_pico_pin_or_castellation_footprint; Mouser Part Number 358-SC0915

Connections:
+3V3: C30.1, C31.1, D2.2 (A), J3.7, J6.4, J7.2, J8.1, L2.1, L6.2, R2.1
+5V: C2.2, C3.2, C27.1, C28.1, D1.2 (A), J7.1, J9.1, L3.2, L4.2, L5.2, R1.1
/CLK0: J3.1, TP10.1, U2.2 (S1)
/CLK1: J3.2, TP11.1, U2.14 (S0)
/CLK2: J3.3, TP12.1
/I_out: J2.T, J10.3, R25.2, TP7.1
/Q_out: J2.R, J10.1, R24.2, TP6.1
/SCL: J3.4, J6.1, U5.2 (GP1)
/SDA: J3.5, J6.2, U5.1 (GP0)
GND: C2.1, C3.1, C5.1, C6.1, C11.1, C12.1, C13.1, C14.1, C15.1, C16.2, C17.1, C18.1, C19.1, C20.1, C22.1, C24.2, C26.1, C27.2, C28.2, C29.1, C30.2, C31.2, G1.1, G2.1, G3.1, G4.1, G5.1, G6.1, G7.1, G8.1, G9.1, G10.1, H1.1, H2.1, H3.1, H4.1, J1.2 (Ext), J2.S, J3.6, J6.3, J7.3, J8.3, J8.8, J8.13, J9.3, J9.8, J10.2, R3.2, R5.2, R13.2, R15.2, R26.2, R27.2, R28.2, U1.2 (GND), U2.8 (GND), U3.4 (V-), U4.4 (V-), U5.3 (GND), U5.8 (GND), U5.13 (GND), U5.18 (GND), U5.23 (GND), U5.28 (GND), U5.33 (AGND), U5.38 (GND)
unnamed: C1.2, U1.1
unnamed 11: C4.1, L1.2, TPa1.1, U1.3; also elsewhere on the board
unnamed: C5.2, R2.2, R3.1, R4.1
unnamed: C10.1, C14.2, R7.1, TP20.1
unnamed: C7.1, C11.2, R8.1, TP3.1
unnamed: C8.1, C12.2, R9.1, TP19.1
unnamed: C9.1, C13.2, R6.1, TP2.1
unnamed: C18.2, R18.1
unnamed: C19.2, R20.1
unnamed: C21.1, R22.2, R24.1, U4.1
unnamed: C21.2, R16.2, R19.1
unnamed: C23.1, R23.2, R25.1, U4.7
unnamed: C23.2, R17.2, R21.1
unnamed: D1.1 (K), R26.1
unnamed: D2.1 (K), R27.1
unnamed: D3.2 (A), J8.15, U5.21 (GP16)
unnamed: D3.1 (K), R28.1
unnamed: C1.1, J1.1 (In), TP8.1
unnamed: J8.2, U5.34 (GP28/ADC2)
unnamed: J8.4, U5.32 (GP27/ADC1)
unnamed: J8.5, U5.31 (GP26/ADC0)
unnamed: J8.6, U5.30 (RUN)
unnamed: J8.7, U5.29 (GP22)
unnamed: J8.9, U5.27 (GP21)
unnamed: J8.10, U5.26 (GP20)
unnamed: J8.11, U5.25 (GP19)
unnamed: J8.12, U5.24 (GP18)
unnamed: J8.14, U5.22 (GP17)
unnamed: J9.2, U5.12 (GP9)
unnamed: J9.4, U5.14 (GP10)
unnamed: J9.5, U5.15 (GP11)
unnamed: J9.6, U5.16 (GP12)
unnamed: J9.7, U5.17 (GP13)
unnamed: J9.9, U5.19 (GP14)
unnamed: J9.10, U5.20 (GP15)
unnamed: L1.1, R1.2
unnamed: R10.2, R16.1, TP4.1, U3.1
unnamed: R11.2, R17.1, TP5.1, U3.7
unnamed 48: C4.2, R4.2, TP1.1, U2.7 (1A), U2.9 (2A); also elsewhere on the board
unnamed: C7.2, U2.6 (1B1), U2.10 (2B1)
unnamed: C9.2, U2.5 (1B2), U2.11 (2B2)
unnamed: C10.2, U2.4 (1B3), U2.12 (2B3)
unnamed: C8.2, U2.3 (1B4), U2.13 (2B4)
unnamed 53: R5.1, TPc1.1, U2.1 (1~OE), U2.15 (2~OE); also elsewhere on the board
unnamed 54: C6.2, L2.2, TPd1.1, U2.16 (VCC); also elsewhere on the board
unnamed 55: R9.2, R12.2, R13.1, TPe1.1, U3.3 (+); also elsewhere on the board
unnamed: R8.2, R10.1, U3.2 (-)
unnamed 57: R7.2, R14.2, R15.1, TPf1.1, U3.5 (+); also elsewhere on the board
unnamed: R6.2, R11.1, U3.6 (-)
unnamed 59: C15.2, C16.1, C17.2, L3.1, R12.1, R14.1, TPg1.1, U3.8 (V+); also elsewhere on the board
unnamed: C20.2, R19.2, U4.3 (+)
unnamed: R18.2, R22.1, U4.2 (-)
unnamed: C22.2, R21.2, U4.5 (+)
unnamed: R20.2, R23.1, U4.6 (-)
unnamed 64: C24.1, L4.1, TPh1.1, U4.8 (V+); also elsewhere on the board
unnamed: C29.2, L6.1, U5.36 (3V3)
unnamed: C26.2, L5.1, U5.40 (VBUS)

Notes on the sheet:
Raises IF voltage to be at DC offset of 2.5 V
T41 V12 schematics: https://github.com/DRWJSCHMIDT/T41/tree/main/T41_V012_Files_01-15-24/T41_V012_Schematic_PDFs
Bias for 1 mA current
Following Figure 2.5 of link below to minimize noise from USB power https://ftdichip.com/wp-content/uploads/2020/08/AN_146_USB_Hardware_Design_Guidelines_for_FTDI_ICs.pdf
Pico's 3.3V buck regulator supplies power for the Si5351 board and mixer
Alternative: OPA2209
21 dB of gain
Alternative: AD8599
"Do not populate" header pins for the Pico to ensure that they are included in the BOM
16 mA bias current thru 62R = 0.99V drop & 4.01V bias for LNA
IQ out Ring - Q Tip - I
22x voltage gain
RF input raised to be symmetric around VCC/2
Corresponds to pinout of Adafruit board https://www.adafruit.com/product/2045 Adafruit board includes I2C pullup resistors
Quadrature LO clock generator
IF Amplifier
Low-pass 200 kHz Anti-aliasing Filter
Quadrature Sampling Detector
Input RF amplifier
Board mounting holes

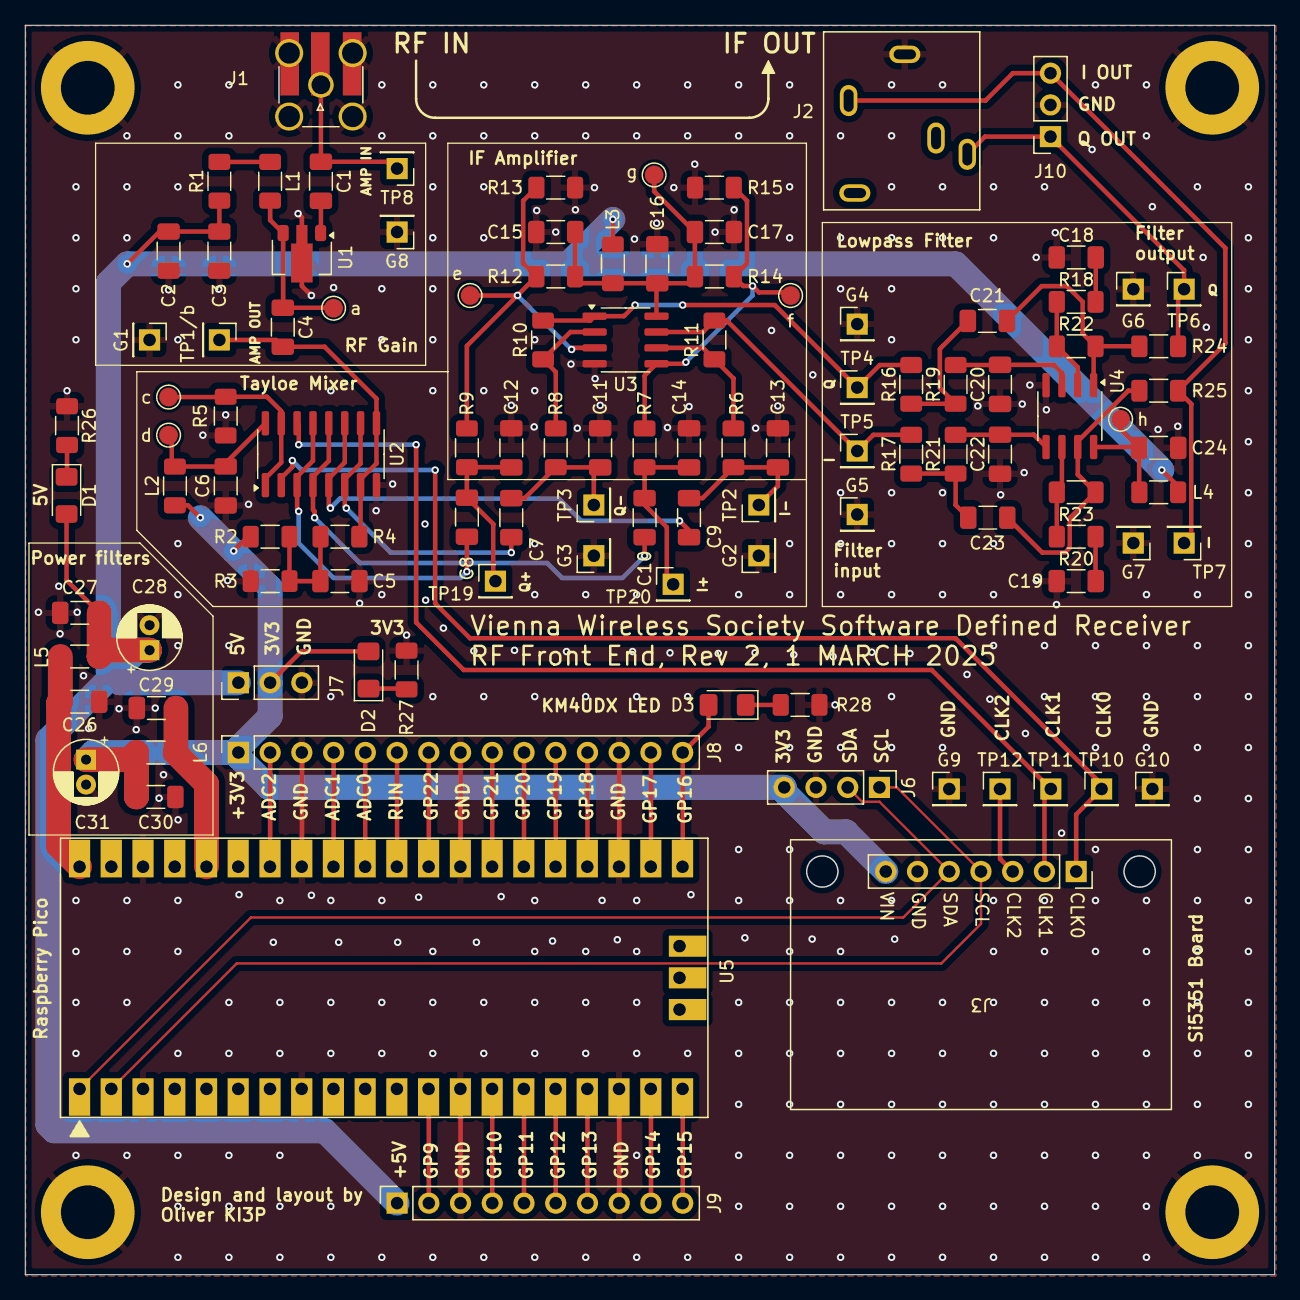
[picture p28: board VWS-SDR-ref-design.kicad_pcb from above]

Board: 4 copper layers, 100.0 x 100.0 mm, 114 parts (0 on the bottom side), 67 nets.

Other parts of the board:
TP1/b: TestPoint; PinHeader_1x01_P2.54mm_Vertical
a: LNA Bias; TestPoint_Pad_D1.5mm
c: Mixer Enable; TestPoint_Pad_D1.5mm
d: Mixer DC; TestPoint_Pad_D1.5mm
e: Q offset; TestPoint_Pad_D1.5mm
f: I offset; TestPoint_Pad_D1.5mm
g: Amp DC; TestPoint_Pad_D1.5mm
h: Filter DC; TestPoint_Pad_D1.5mm

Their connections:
unnamed 11: a.1; also elsewhere on the board
unnamed 48: TP1/b.1; also elsewhere on the board
unnamed 53: c.1; also elsewhere on the board
unnamed 54: d.1; also elsewhere on the board
unnamed 55: e.1; also elsewhere on the board
unnamed 57: f.1; also elsewhere on the board
unnamed 59: g.1; also elsewhere on the board
unnamed 64: h.1; also elsewhere on the board

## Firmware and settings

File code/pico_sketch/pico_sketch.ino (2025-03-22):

/*
 * Credit to the T41 project (https://github.com/KI3P/T41-V12-SDT) for the code that 
 * controls the Si5351.
 *
 * Oliver KI3P, March 2025
 */

#include <Ticker.h>
#include "si5351.h"

#define SI5351_LOAD_CAPACITANCE SI5351_CRYSTAL_LOAD_8PF
#define SI5351_DRIVE_CURRENT SI5351_DRIVE_8MA
#define SI5351_FREQ_CORRECTION_FACTOR 0
#define Si_5351_crystal 25000000L
#define SDA 0
#define SCL 1
#define FREQ_MIN_HZ 100000
#define FREQ_MAX_HZ 200000000
#define LED_PIN 16

Si5351 si5351;
long centerFreq;
long IFFreq;
long long Clk1SetFreq; 
long long Clk0SetFreq;
int multiple;
int oldMultiple;
long long pll_freq;
long long freq;
bool LED_state;
char strBufRes[100];

Ticker toggler;
const float togglePeriod = 1;  //seconds

void toggle() {
  digitalWrite(LED_PIN, !digitalRead(LED_PIN));
}

int EvenDivisor(long freq2) {
  // next 6 ifs added by DRM VK3KQT for use by a phase method of time delay described by
  // https://tj-lab.org/2020/08/27/si5351単体で3mhz以下の直交信号を出力する/
  // for below 3.2MHz the ~limit of PLLA @ 400MHz for a 126 divider
  if (freq2 < 100000)
      multiple = 8192;

  if ((freq2 >= 100000) && (freq2 < 200000))   // PLLA 409.6 MHz to 819.2 MHz
     multiple = 4096;
  
  if ((freq2 >= 200000) && (freq2 < 400000))   //   ""          "" 
     multiple = 2048;

  if ((freq2 >= 400000) && (freq2 < 800000))   //    ""          ""
     multiple = 1024;

  if ((freq2 >= 800000) && (freq2 < 1600000))   //    ""         ""
     multiple = 512;

  if ((freq2 >= 1600000) && (freq2 < 3200000))   //    ""        ""
     multiple = 256;
   //==================================================================  
  // the original multiple
  // if (freq2 < 6850000)
  if ((freq2 >= 3200000) && (freq2 < 6850000))   // 403.2 MHz - 863.1 MHz
    multiple = 126;

  if ((freq2 >= 6850000) && (freq2 < 9500000))
    multiple = 88;

  if ((freq2 >= 9500000) && (freq2 < 13600000))
    multiple = 64;

  if ((freq2 >= 13600000) && (freq2 < 17500000))
    multiple = 44;

  if ((freq2 >= 17500000) && (freq2 < 25000000))
    multiple = 34;

  if ((freq2 >= 25000000) && (freq2 < 36000000))
    multiple = 24;

  if ((freq2 >= 36000000) && (freq2 < 45000000))
    multiple = 18;

  if ((freq2 >= 45000000) && (freq2 < 60000000))
    multiple = 14;

  if ((freq2 >= 60000000) && (freq2 < 80000000))
    multiple = 10;

  if ((freq2 >= 80000000) && (freq2 < 100000000))
    multiple = 8;

  if ((freq2 >= 100000000) && (freq2 < 150000000)) // G0ORX changed upper limit
    multiple = 6;

  if ((freq2 >= 150000000) && (freq2 < 220000000))
    multiple = 4;

  // ? G0ORX - for higher bands
  if(freq2>=220000000) {
    multiple = 2;
  }
  return multiple;
}

void SetFreq() {   // reworked VK3KQT

  long long f=centerFreq;
  Clk1SetFreq = ((f * SI5351_FREQ_MULT) + IFFreq * SI5351_FREQ_MULT);
  multiple = EvenDivisor(Clk1SetFreq / SI5351_FREQ_MULT);
  pll_freq = Clk1SetFreq * multiple;
  freq = pll_freq / multiple;     // is this equal to Clk1SetFreq?
  
  if ( multiple == oldMultiple) {               // Still within the same multiple range 
      si5351.set_pll(pll_freq, SI5351_PLLA);    // just change PLLA on each frequency change of encoder
                                                // this minimizes I2C data for each frequency change within a 
                                                // multiple range
  }
  else { 
    if ( multiple <= 126) {                                 // this the library setting of phase for freqs
        si5351.set_freq_manual(freq, pll_freq, SI5351_CLK0);  // greater than 3.2MHz where multiple is <= 126
        si5351.set_freq_manual(freq, pll_freq, SI5351_CLK1);   // set both clocks to new frequency
        si5351.set_phase(SI5351_CLK0, 0);                      // CLK0 phase = 0 
        si5351.set_phase(SI5351_CLK1, multiple);               // Clk1 phase = multiple for 90 degrees(digital delay)
        si5351.pll_reset(SI5351_PLLA);                         // reset PLLA to align outputs 
        si5351.output_enable(SI5351_CLK0, 1);                  // set outputs on or off
        si5351.output_enable(SI5351_CLK1, 1);
        si5351.output_enable(SI5351_CLK2, 0);
    }
    else {        // this is the timed delay technique for frequencies below 3.2MHz as detailed in 
                  // https://tj-lab.org/2020/08/27/si5351単体で3mhz以下の直交信号を出力する/
        // cli and sei need to be disabled on Pico for some reason. Isn't a problem because
        // we don't use any interrupts in this simple code.
        //cli();                //__disable_irq(); or __enable_irq();     // or cli()/sei() pair; needed to get accurate timing??
        //si5351.output_enable(SI5351_CLK0, 0);  // optional switch off clocks if audio effects are generated
        //si5351.output_enable(SI5351_CLK1, 0);  //  with the change of multiple below 3.2MHz
        si5351.set_freq_manual((freq - 400ULL), pll_freq, SI5351_CLK0);  // set up frequencies of CLK 0/1 4 Hz low
        si5351.set_freq_manual((freq - 400ULL), pll_freq, SI5351_CLK1);  // as per TJ-Labs article 
        si5351.set_phase(SI5351_CLK0, 0);                          // set phase registers to 0 just to be sure
        si5351.set_phase(SI5351_CLK1, 0);                          
        si5351.pll_reset(SI5351_PLLA);                             // align both clockss in phase
        si5351.set_freq_manual(freq, pll_freq, SI5351_CLK0);       // set clock 0  to required freq
        //delayNanoseconds(625000000);       // 62.5 * 1000000      //configured for a 62.5 mSec delay at 4 Hz difference 
        delayMicroseconds(58500);                       //nominally 62500 this figure can be adjusted for a more exact delay which is phase
        si5351.set_freq_manual(freq, pll_freq, SI5351_CLK1);       // set CLK 1 to the required freq after delay
        //sei();
        si5351.output_enable(SI5351_CLK0, 1);                      // switch them on to be sure
        si5351.output_enable(SI5351_CLK1, 1);                      //    ""        ""
        si5351.output_enable(SI5351_CLK2, 0);
      }
  }
  oldMultiple = multiple;
}

void scanner() {
  byte error, address;
  int nDevices;

  Serial.println("Scanning...");

  nDevices = 0;
  for(address = 1; address < 127; address++ )
  {
    // The i2c_scanner uses the return value of
    // the Write.endTransmisstion to see if
    // a device did acknowledge to the address.
    Wire.beginTransmission(address);
    error = Wire.endTransmission();

    if (error == 0)
    {
      Serial.print("I2C device found at address 0x");
      if (address<16)
        Serial.print("0");
      Serial.print(address,HEX);
      Serial.println("  !");

      nDevices++;
    }
    else if (error==4)
    {
      Serial.print("Unknown error at address 0x");
      if (address<16)
        Serial.print("0");
      Serial.println(address,HEX);
    }
  }
  if (nDevices == 0)
    Serial.println("No I2C devices found\n");
  else
    Serial.println("done\n");

}

void setup() {
  pinMode(LED_BUILTIN, OUTPUT); // Set LED_BUILTIN as an output pin
  digitalWrite(LED_BUILTIN, HIGH);

  Serial.begin(115200);
  delay(500);
  Wire.setSDA(SDA);
  Wire.setSCL(SCL);

  while (!si5351.init(SI5351_LOAD_CAPACITANCE, Si_5351_crystal, SI5351_FREQ_CORRECTION_FACTOR)){
    Serial.println("Unable to connect to Si5351");
    scanner();
    delay(3000);
  }
  si5351.drive_strength(SI5351_CLK0, SI5351_DRIVE_CURRENT);
  si5351.drive_strength(SI5351_CLK1, SI5351_DRIVE_CURRENT);
  si5351.set_ms_source(SI5351_CLK0, SI5351_PLLA);
  si5351.set_ms_source(SI5351_CLK1, SI5351_PLLA);

  IFFreq = 0;
  centerFreq = 10000000;
  SetFreq();

  pinMode(LED_PIN, OUTPUT);
  digitalWrite(LED_PIN, LOW);  // make sure LED is off on start
  toggler.attach(togglePeriod, toggle);
  digitalWrite(LED_BUILTIN, LOW);
}

int read_input(String *command, int *value){
  String selection = Serial.readString();  //read until timeout
  selection.trim();                        // remove any \r \n whitespace at the end of the String
  selection.toUpperCase();
  // We receive strings in the form "CM VALUE". Check for valid formatting
  if (selection.length() < 4){
    sprintf(strBufRes,"Command string too short! Length %d < mininimum length 4: ",selection.length());
    Serial.print(strBufRes);
    Serial.println(selection);
    return 1;
  }
  if (selection[2] != ' '){
    sprintf(strBufRes,"3rd character must be a space: ",selection);
    Serial.print(strBufRes);
    Serial.println(selection);
    return 1;
  }
  String value_str = selection.substring(3);
  *command = selection.substring(0, 2);
  *value = value_str.toInt();
  return 0;
}

void loop() {
  Serial.println("ENTER FREQUENCY IN HZ:");
  Serial.println("FR 123456");

  while (Serial.available() == 0) {
  }     //wait for data available
  String command;
  int value;
  if (!read_input(&command, &value)) {      
    if (command == "FR"){
      if ((value >= FREQ_MIN_HZ) & (value <= FREQ_MAX_HZ)){
        centerFreq = value;
        SetFreq();
        Serial.println("OK");
      } else {
        sprintf(strBufRes,"Frequency %d outside of valid range %d to %d!\n",value,FREQ_MIN_HZ,FREQ_MAX_HZ);
        Serial.print(strBufRes);
      }
    } else if (command == "TX") {
        digitalWrite(LED_BUILTIN, value); // Toggle LED
    } else {
      Serial.print("Unrecognized command: ");
      Serial.println(command);
    }
  }

}

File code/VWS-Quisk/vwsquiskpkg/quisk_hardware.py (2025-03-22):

import configure
from quisk_hardware_model import Hardware as BaseHardware
import _quisk as QS
import serial

################ Receivers VWS SDR, A receiver designed by KI3P.
## hardware_file_name		Hardware file path, rfile
# This is the file that contains the control logic for each radio.
#hardware_file_name = "vwsquiskpkg/quisk_hardware.py"

## widgets_file_name			Widget file path, rfile
# This optional file adds additional controls for the radio.
#widgets_file_name = ""

## rx_max_amplitude_correct		Max ampl correct, number
# If you get your I/Q samples from a sound card, you will need to correct the
# amplitude and phase for inaccuracies in the analog hardware.  The correction is
# entered using the controls from the "Rx Phase" button on the config screen.
# You must enter a positive number.  This controls the range of the control.
#rx_max_amplitude_correct = 0.42

## rx_max_phase_correct			Max phase correct, number
# If you get your I/Q samples from a sound card, you will need to correct the
# amplitude and phase for inaccuracies in the analog hardware.  The correction is
# entered using the controls from the "Rx Phase" button on the config screen.
# You must enter a positive number.  This controls the range of the control in degrees.
#rx_max_phase_correct = 10.0

## vws_name                   Serial port, text
# The name of the VWS serial port to open.
#vws_name = "com5"

sample_rate = 48000
channel_i = 0
channel_q = 1
correction = 630

class Hardware(BaseHardware):
  def __init__(self, app, conf):
    BaseHardware.__init__(self, app, conf)
          
  def open(self):
    text = BaseHardware.open(self)
    self.serial = serial.Serial(getattr(self.conf, "vws_name"),115200)
    self.vfo = None
    self.tune = None
    return text

  def close(self):
    del self.serial
    self.vfo = None
    self.tune = None
    pass

  def ChangeFrequency(self, tune, vfo, source='', band='', event=None):
    if vfo != self.vfo:
      self.serial.write(b'FR %d\n'%(vfo+correction))
      self.vfo = vfo
    self.tune = tune
    return [self.tune, self.vfo]

  def ReturnFrequency(self):
    return [self.tune, self.vfo]
  
  def ImmediateChange(self, name):
    pass
  
  def PollGuiControl(self):
    pass

  #
  # On PTT Button press send value to send TX command 
  # TX 1 = PTT on
  # TX 2 = PTT off
  #
  def OnButtonPTT(self, event):
    btn = event.GetEventObject()
    self.serial.write(b'TX %d\n'%(btn.GetValue()))
  #  print ('TX %d'%(btn.GetValue()))

  

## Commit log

2025-01-09 Added the KiCad files containing the reference schematic
    [VWS-SDR-ref-design.kicad_pcb, VWS-SDR-ref-design.kicad_sch]
2025-01-25 Placement complete, next step routing
    [VWS-SDR-ref-design.kicad_pcb, VWS-SDR-ref-design.kicad_sch]
2025-01-25 Layout complete
    [VWS-SDR-ref-design.kicad_pcb]
2025-02-16 Added part selection
    [VWS-SDR-ref-design.kicad_pcb, VWS-SDR-ref-design.kicad_sch]
2025-02-17 Basic software for pico and gnuradio interface to control it
2025-02-22 Added BOM
    [VWS_SDR_BOM.csv, VWS_SDR_BOM.ods]
2025-03-22 Update for Rev 2 of the board
    [VWS-SDR-ref-design.kicad_pcb, VWS-SDR-ref-design.kicad_sch, VWS_SDR_BOM.csv]
2025-03-22 Turn an LED on during setup for testing purposes
2025-05-31 Improvements to the gnuradio flowgraph

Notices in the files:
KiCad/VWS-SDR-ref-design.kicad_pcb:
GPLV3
